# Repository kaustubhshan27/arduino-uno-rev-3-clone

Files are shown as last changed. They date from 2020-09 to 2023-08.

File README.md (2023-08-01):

# Arduino-Uno-Rev-3-Clone
Implemented an Arduino Uno Rev 3 PCB clone using Altium Designer. All component symbols and footprints were made from scratch.

## Assembly View
Screenshot from 2023-08-01 13-02-20

## Schematic
Screenshot from 2023-08-01 13-00-51

## 3D
Screenshot from 2023-08-01 13-01-30

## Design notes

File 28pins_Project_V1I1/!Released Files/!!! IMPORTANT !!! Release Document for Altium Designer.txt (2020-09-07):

Follow this procedure before releasing files. Confirm every action with your initials and date.
IF ANY CHANGES NEEDS TO BE DONE, START THE PROCEDURE FROM BEGINNING!

The procedure needs to be executed in order as defined here. Start from number 1
--------------------------------------------------------------------------------

1) Right Click on the project -> Compile PCB project
I confirm, the project compiles with no errors: 
KS [07-09-2020]

2) Run Design -> Update PCB Document
I confirm, there are no differences between Schematic and PCB: 
KS [07-09-2020]

3) Impedance
I confirm, I have updated and check track width/gap to match required impedance (e.g 55 OHMs): 
NA

4) Run Tools -> Polygon Pours -> Rebuild All
I confirm, all polygons have been repoured: 
KS [07-09-2020]

5) Run Tools -> Design Rule Check -> Run Design Rule Check
I confirm, I have checked Design Rule Output File:
KS [07-09-2020]

6) Gerber check
I confirm, I have copied and visually checked gerber files placed in \PCB Manufacturing\Gerber Output\
KS [07-09-2020]

7) Other files
I confirm, I have copied and checked files placed in subdirectories:
KS [07-09-2020]

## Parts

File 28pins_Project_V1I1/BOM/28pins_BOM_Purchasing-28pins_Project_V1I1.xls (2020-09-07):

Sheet: Part List Report
 | Component list |  |  | 28pins_BOM_Purchasing for Project [28pins_Project_V1I1.PrjPcb] (No PCB Document Selected)
 | Source Data From: | 28pins_Project_V1I1.PrjPcb |  |  | Contact: |  |  |  | Generated by:
 | Project: | 28pins_Project_V1I1.PrjPcb
 | Variant: | None |  |  |  |  |  |  | FEDEVEL
 | Report Date: | 30-Aug-20 | 10:42 PM |  |  |  |  |  | http://www.fedevel.com
 | Print Date: | 2020-08-30 | 22:42:14
# | Category | Manufacturer 1 | Manufacturer Part Number 1 | #Column Name Error:' Package / Case | Description | Quantity | Supplier 1 | Supplier Part Number 1 | Supplier Order Qty 1 | Supplier Stock 1 | Supplier Unit Price 1 | Supplier Subtotal 1 | Supplier Currency 1
1 | Aluminum Electrolytic Capacitors | Panasonic | EEE-1AA101WR |  | Cap Aluminum 100uF 10V 20% (5 X 5.4mm) SMD 50mA 1000 hr 85°C T/R | 2 | Digi-Key | PCE3867CT-ND | 2 | 0 | 0.30 | 0.60 | USD
2 | Ceramic Capacitors | TDK | C2012X5R1C106M125AC |  | CERAMIC CAPACITOR, 10UF, 16V, X5R, 20%, 0805, FULL REEL; Product Range:C Series; Capacitance:10 F; Capacitance Tolerance: 20%; Dielectric Characteristic:X5R; Voltage Rating:16V; Ceramic Capacitor Case:0805 [2012 Metric]; MSL:- ;RoHS Compliant: Yes | 7 | Digi-Key | 445-4115-2-ND |  | 0
3 | Ceramic Capacitors | TDK | C2012X7R1H104K085AA |  | TDK - C2012X7R1H104K085AA - SMD Multilayer Ceramic Capacitor, 0.1 µF, 50 V, 0805 [2012 Metric], ± 10%, X7R, C Series | 19 | Digi-Key | 445-7534-1-ND | 19 | 0 | 0.11 | 2.17 | USD
4 | Ceramic Capacitors | TDK | C2012X5R1E105K125AA |  | TDK - C2012X5R1E105K125AA - SMD Multilayer Ceramic Capacitor, 1 µF, 25 V, 0805 [2012 Metric], ± 10%, X5R, C Series | 1 | Digi-Key | 445-1419-1-ND | 1 | 10418 | 0.26 | 0.26 | USD
5 | Ceramic Capacitors | KEMET | C0805C180J5GACTU |  | CAP CER 18PF 50V C0G/NP0 0805 | 4 | Digi-Key | 399-1112-1-ND | 4 | 107048 | 0.13 | 0.52 | USD
6 | Uncategorized | Osram Opto | LGL29K-G2J1-24-Z |  | LED Uni-Color Green 572nm 2-Pin Chip 0603(1608Metric) T/R | 1 | Digi-Key | 475-2709-1-ND | 1 | 0 | 0.42 | 0.42 | USD
7 | Uncategorized | Osram Opto | LOL29K-H2K1-24-Z |  | OSRAM - LO L29K-H2K1-24-Z - SMARTLED 0603 ORANGE | 3 | Digi-Key | 475-2740-2-ND |  | 0
8 | Schottky Diodes | ON Semiconductor / Fairchild | BAT54HT1G |  | Small Signal Schottky Diode, Single, 30 V, 200 mA, 800 mV, 600 mA, 150 C ;RoHS Compliant: Yes | 2 | Digi-Key | BAT54HT1GOSCT-ND | 2 | 217747 | 0.20 | 0.40 | USD
9 | Ferrite Beads and Chips | TDK | MPZ2012S601AT000 |  | FERRITE BEAD 600 OHM 0805 1LN | 3 | Digi-Key | 445-2206-1-ND | 3 | 217659 | 0.11 | 0.33 | USD
10 | Headers and Wire Housings | Harwin | M20-7820842 |  | 2.54mm (0.1") Pitch SIL Vertical PC Tail Socket Assembly, selective gold + tin, 8 contacts | 2 | Digi-Key | 952-1823-ND | 2 | 1791 | 1.10 | 2.20 | USD
11 | Headers and Wire Housings | Harwin | M20-7820646 |  | 06-WAY SIL VERT SOCKET L/FREE | 1 | Digi-Key | 952-1809-ND | 1 | 2278 | 0.96 | 0.96 | USD
12 | Headers and Wire Housings | Harwin | M20-7821046 |  | HARWIN - M20-7821046 - Board-To-Board Connector, M20 Series, Through Hole, Receptacle, 10, 2.54 mm, Tin Plated Contacts | 1 | Digi-Key | 952-1847-ND | 1 | 554 | 1.28 | 1.28 | USD
13 | Headers and Wire Housings | Harwin | M20-9980346 |  | Conn Unshrouded Header HDR 6 POS 2.54mm Solder ST Thru-Hole Bag | 2 | Digi-Key | 952-2121-ND | 2 | 18299 | 0.24 | 0.48 | USD
14 | USB Connectors | AMPHENOL ICC (FCI) | 10118193-0001LF |  | CONN USB MICRO B RECPT SMT R/A | 1 | Digi-Key | 609-4616-1-ND | 1 | 126829 | 0.43 | 0.43 | USD
15 | Headers and Wire Housings | Harwin | M20-9990346 |  | CONN HEADER VERT 3POS 2.54MM | 2 | Digi-Key | 952-2264-ND | 2 | 11198 | 0.15 | 0.30 | USD
16 | Headers and Wire Housings | Amphenol ICC | 68602-204HLF |  | CONN HEADER VERT 4POS 2.54MM | 1 | Digi-Key | 609-3369-ND | 1 | 3699 | 0.34 | 0.34 | USD
17 | Headers and Wire Housings | Harwin | M20-9990446 |  | 04 SIL Vert Pin Hdr | 1 | Digi-Key | 952-2266-ND | 1 | 10513 | 0.19 | 0.19 | USD
18 | Fixed Inductors | KEMET | L1210R2R2MDWIT |  | FIXED IND 2.2UH 2A 80 MOHM SMD | 1 | Digi-Key | 399-9598-1-ND | 1 | 0 | 0.50 | 0.50 | USD
19 | Connectors | Sullins | QPC02SXGN-RC |  | CONN JUMPER SHORTING .100" GOLD | 3 | Digi-Key | S9337-ND | 3 | 588896 | 0.10 | 0.30 | USD
20 | Chip SMD Resistors | Yageo | RC0805FR-07100KL |  | YAGEO RC0805FR-07100KL RES, THICK FILM, 100K, 1%, 0.125W, 0805, REEL | 1 | Digi-Key | 311-100KCRCT-ND | 1 | 3710722 | 0.10 | 0.10 | USD
21 | Chip SMD Resistors | Yageo | RC0805FR-07560RL |  | Surface Mount Thick Film Resistor, RC Series, 560 ohm, 125 mW, - 1%, 150 V, 0805 [2012 Metric] | 5 | Digi-Key | 311-560CRCT-ND | 5 | 75023 | 0.10 | 0.50 | USD
22 | Chip SMD Resistors | Yageo | RC0805FR-0710KL |  | RES SMD 10K OHM 1% 1/8W 0805 | 6 | Digi-Key | 311-10.0KCRCT-ND | 6 | 19063106 | 0.10 | 0.60 | USD
23 | Chip SMD Resistors | Yageo | RC0805FR-0722RL |  | RES SMD 22 OHM 1% 1/8W 0805 | 7 | Digi-Key | 311-22.0CRCT-ND | 7 | 736981 | 0.10 | 0.70 | USD
24 | Chip SMD Resistors | Yageo | RC0805JR-070RL |  | Surface Mount Thick Film Resistor, RC Series, 125 mW, - 5%, 150 V, 0805 [2012 Metric] | 4 | Digi-Key | 311-0.0ARCT-ND | 4 | 6537793 | 0.10 | 0.40 | USD
25 | Chip SMD Resistors | Yageo | RC0805FR-071ML |  | RES SMD 1M OHM 1% 1/8W 0805 | 2 | Digi-Key | 311-1.00MCRCT-ND | 2 | 2931267 | 0.10 | 0.20 | USD
26 | Chip SMD Resistors | Yageo | RC0805FR-071KL |  | RESISTOR, 0805 1K 1%, FULL REEL; Product Range:YAGEO - RC Series; Resistance:1kohm; Power Rating:125mW; Resistance Tolerance:± 1%; Resistor Case Style:0805 [2012 Metric]; Resistor Element Material:Thick Film; Temperature Coefficient:± 250ppm/°C; Voltage Rating:150V; Packaging:Tape & Reel; MSL:-; SVHC:No SVHC (16-Dec-2013); External Depth:0.55mm; External Length / Height:2mm; External Width:1.25mm; No. of Pins:2; Operating Temperature Max:155°C; Operating Temperature Min:-55°C; Operating Temperature Range:-55°C to +155°C; Reel Quantity:5000; Resistor Mounting:SMD; Series:RC12H; Temperature Coef | 3 | Digi-Key | 311-1.00KCRCT-ND | 3 | 17310766 | 0.10 | 0.30 | USD
27 | Connectors | 3M | 7010501790 |  | CONN IC DIP SOCKET 28POS TIN | 1 | Digi-Key | 3M5480-ND | 1 | 4178 | 0.79 | 0.79 | USD
28 | Pushbutton Switches | TE Connectivity | FSM4JH |  | SWITCH TACTILE SPST-NO 0.05A 24V | 2 | Digi-Key | 450-1650-ND | 2 | 94987 | 0.10 | 0.20 | USD
29 | Microcontrollers | Microchip / Atmel | ATMEGA328P-PU |  | ATMEGA328P-PU; 8 bit Microcontroller AVR 20MHz 1; 32kb Flash; 2kb RAM; I2C SPI 2 | 1 | Digi-Key | ATMEGA328P-PU-ND | 1 | 4823 | 2.08 | 2.08 | USD
30 | Microcontrollers | Microchip | ATMEGA16U2-AU |  | MICROCHIP - ATMEGA16U2-AU - MCU, 8BIT, MEGAAVR, 16MHZ, TQFP-32 | 1 | Digi-Key | ATMEGA16U2-AU-ND | 1 | 3865 | 2.45 | 2.45 | USD
31 | Voltage Regulators - Linear | Texas Instruments | TL1963A-33DCQR |  | IC REG LINEAR 3.3V 1.5A SOT223-6 | 1 | Digi-Key | 296-24534-1-ND | 1 | 2906 | 2.80 | 2.80 | USD
32 | Logic Gates | Texas Instruments | SN74AHC1G09DBVR |  | TEXAS INSTRUMENTS - SN74AHC1G09DBVR - AND Gate, 74AHC1G09, 2 Input, 2 V to 5.5 V, SOT-23-5 | 4 | Digi-Key | 296-29202-1-ND | 4 | 30506 | 0.32 | 1.28 | USD
33 | Crystals | Abracon | ABM7-16.000MHZ-D2Y-T |  | CRYSTAL 16.0000MHZ 18PF SMD | 2 | Digi-Key | 535-9840-1-ND | 2 | 61243 | 1.00 | 2.00 | USD
34 | Varistors | Bourns | CG0603MLC-05E |  | VARISTOR 0603 | 2 | Digi-Key | CG0603MLC-05ECT-ND | 2 | 106625 | 0.10 | 0.20 | USD
 |  |  |  |  |  | 99 |  |  | 89 |  |  | 26.28
Approved |  |  |  | Notes
 |  |  |  |  |  | 1 | pcs: | Total |  | 26.28 |  | USD
 |  |  |  |  |  |  |  | Price for 1pcs |  | 26.28 |  | USD

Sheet: Project Information
Project Full Path | C:\Users\Public\Documents\Altium\Projects\28pins_Project_V1I1\28pins_Project_V1I1.PrjPcb
Project Filename | 28pins_Project_V1I1.PrjPcb
Variant Name | None
Data-Source Filename | 28pins_Project_V1I1.PrjPcb
Data-Source Full Path | C:\Users\Public\Documents\Altium\Projects\28pins_Project_V1I1\28pins_Project_V1I1.PrjPcb
Title | 28pins_BOM_Purchasing for Project [28pins_Project_V1I1.PrjPcb] (No PCB Document Selected)
Total Quantity | 99
Report Time | 10:42 PM
Report Date | 30-Aug-20
Report Date & Tine | 30-Aug-20 10:42 PM
Output Name | 28pins_BOM_Purchasing
Output Type | BOM_PartType
Output Generator Name | BOM
Output Generator Description | Bill of Materials

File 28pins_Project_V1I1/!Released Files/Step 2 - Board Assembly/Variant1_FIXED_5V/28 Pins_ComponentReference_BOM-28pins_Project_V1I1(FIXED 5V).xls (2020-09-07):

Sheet: Part List Report
 | Component reference list |  |  | <Parameter Project not found>
 |  | Source Data From: | 28pins_Project_V1I1.PrjPcb |  | Contact: |  | Generated by:
 |  | Project: | 28pins_Project_V1I1.PrjPcb
 |  | Variant: | FIXED 5V |  |  |  | FEDEVEL
 | Report Date: | 07-Sep-20 | 11:49 AM |  |  |  | http://www.fedevel.com
 | Print Date: | 2020-09-07 | 11:49:17
# | Designator | Comment | Description | Manufacturer 1 | Manufacturer Part Number 1 | #Column Name Error:' Package / Case | Supplier 1 | Supplier Part Number 1
1 | C1 | 100uF/10V | Cap Aluminum 100uF 10V 20% (5 X 5.4mm) SMD 50mA 1000 hr 85°C T/R |  |  |  | Digi-Key | PCE3867CT-ND
2 | C2 | 100uF/10V | Cap Aluminum 100uF 10V 20% (5 X 5.4mm) SMD 50mA 1000 hr 85°C T/R |  |  |  | Digi-Key | PCE3867CT-ND
3 | C3 | 10uF/16V | CERAMIC CAPACITOR, 10UF, 16V, X5R, 20%, 0805, FULL REEL; Product Range:C Series; Capacitance:10 F; Capacitance Tolerance: 20%; Dielectric Characteristic:X5R; Voltage Rating:16V; Ceramic Capacitor Case:0805 [2012 Metric]; MSL:- ;RoHS Compliant: Yes |  |  |  | Digi-Key | 445-4115-2-ND
4 | C4 | 100nF/50V | TDK - C2012X7R1H104K085AA - SMD Multilayer Ceramic Capacitor, 0.1 µF, 50 V, 0805 [2012 Metric], ± 10%, X7R, C Series |  |  |  | Digi-Key | 445-7534-1-ND
5 | C5 | 100nF/50V | TDK - C2012X7R1H104K085AA - SMD Multilayer Ceramic Capacitor, 0.1 µF, 50 V, 0805 [2012 Metric], ± 10%, X7R, C Series |  |  |  | Digi-Key | 445-7534-1-ND
6 | C6 | 100nF/50V | TDK - C2012X7R1H104K085AA - SMD Multilayer Ceramic Capacitor, 0.1 µF, 50 V, 0805 [2012 Metric], ± 10%, X7R, C Series |  |  |  | Digi-Key | 445-7534-1-ND
7 | C7 | 1uF/25V | TDK - C2012X5R1E105K125AA - SMD Multilayer Ceramic Capacitor, 1 µF, 25 V, 0805 [2012 Metric], ± 10%, X5R, C Series |  |  |  | Digi-Key | 445-1419-1-ND
8 | C8 | 100nF/50V | TDK - C2012X7R1H104K085AA - SMD Multilayer Ceramic Capacitor, 0.1 µF, 50 V, 0805 [2012 Metric], ± 10%, X7R, C Series |  |  |  | Digi-Key | 445-7534-1-ND
9 | C9 | 18pF/50V | CAP CER 18PF 50V C0G/NP0 0805 |  |  |  | Digi-Key | 399-1112-1-ND
10 | C10 | 18pF/50V | CAP CER 18PF 50V C0G/NP0 0805 |  |  |  | Digi-Key | 399-1112-1-ND
11 | C11 | 100nF/50V | TDK - C2012X7R1H104K085AA - SMD Multilayer Ceramic Capacitor, 0.1 µF, 50 V, 0805 [2012 Metric], ± 10%, X7R, C Series |  |  |  | Digi-Key | 445-7534-1-ND
12 | C12 | 10uF/16V | CERAMIC CAPACITOR, 10UF, 16V, X5R, 20%, 0805, FULL REEL; Product Range:C Series; Capacitance:10 F; Capacitance Tolerance: 20%; Dielectric Characteristic:X5R; Voltage Rating:16V; Ceramic Capacitor Case:0805 [2012 Metric]; MSL:- ;RoHS Compliant: Yes |  |  |  | Digi-Key | 445-4115-2-ND
13 | C13 | 10uF/16V | CERAMIC CAPACITOR, 10UF, 16V, X5R, 20%, 0805, FULL REEL; Product Range:C Series; Capacitance:10 F; Capacitance Tolerance: 20%; Dielectric Characteristic:X5R; Voltage Rating:16V; Ceramic Capacitor Case:0805 [2012 Metric]; MSL:- ;RoHS Compliant: Yes |  |  |  | Digi-Key | 445-4115-2-ND
14 | C14 | 100nF/50V | TDK - C2012X7R1H104K085AA - SMD Multilayer Ceramic Capacitor, 0.1 µF, 50 V, 0805 [2012 Metric], ± 10%, X7R, C Series |  |  |  | Digi-Key | 445-7534-1-ND
15 | C15 | 100nF/50V | TDK - C2012X7R1H104K085AA - SMD Multilayer Ceramic Capacitor, 0.1 µF, 50 V, 0805 [2012 Metric], ± 10%, X7R, C Series |  |  |  | Digi-Key | 445-7534-1-ND
16 | C16 | 100nF/50V | TDK - C2012X7R1H104K085AA - SMD Multilayer Ceramic Capacitor, 0.1 µF, 50 V, 0805 [2012 Metric], ± 10%, X7R, C Series |  |  |  | Digi-Key | 445-7534-1-ND
17 | C17 | 100nF/50V | TDK - C2012X7R1H104K085AA - SMD Multilayer Ceramic Capacitor, 0.1 µF, 50 V, 0805 [2012 Metric], ± 10%, X7R, C Series |  |  |  | Digi-Key | 445-7534-1-ND
18 | C19 | 10uF/16V | CERAMIC CAPACITOR, 10UF, 16V, X5R, 20%, 0805, FULL REEL; Product Range:C Series; Capacitance:10 F; Capacitance Tolerance: 20%; Dielectric Characteristic:X5R; Voltage Rating:16V; Ceramic Capacitor Case:0805 [2012 Metric]; MSL:- ;RoHS Compliant: Yes |  |  |  | Digi-Key | 445-4115-2-ND
19 | C20 | 100nF/50V | TDK - C2012X7R1H104K085AA - SMD Multilayer Ceramic Capacitor, 0.1 µF, 50 V, 0805 [2012 Metric], ± 10%, X7R, C Series |  |  |  | Digi-Key | 445-7534-1-ND
20 | C21 | 10uF/16V | CERAMIC CAPACITOR, 10UF, 16V, X5R, 20%, 0805, FULL REEL; Product Range:C Series; Capacitance:10 F; Capacitance Tolerance: 20%; Dielectric Characteristic:X5R; Voltage Rating:16V; Ceramic Capacitor Case:0805 [2012 Metric]; MSL:- ;RoHS Compliant: Yes |  |  |  | Digi-Key | 445-4115-2-ND
21 | C22 | 10uF/16V | CERAMIC CAPACITOR, 10UF, 16V, X5R, 20%, 0805, FULL REEL; Product Range:C Series; Capacitance:10 F; Capacitance Tolerance: 20%; Dielectric Characteristic:X5R; Voltage Rating:16V; Ceramic Capacitor Case:0805 [2012 Metric]; MSL:- ;RoHS Compliant: Yes |  |  |  | Digi-Key | 445-4115-2-ND
22 | C23 | 100nF/50V | TDK - C2012X7R1H104K085AA - SMD Multilayer Ceramic Capacitor, 0.1 µF, 50 V, 0805 [2012 Metric], ± 10%, X7R, C Series |  |  |  | Digi-Key | 445-7534-1-ND
23 | C24 | 100nF/50V | TDK - C2012X7R1H104K085AA - SMD Multilayer Ceramic Capacitor, 0.1 µF, 50 V, 0805 [2012 Metric], ± 10%, X7R, C Series |  |  |  | Digi-Key | 445-7534-1-ND
24 | C25 | 18pF/50V | CAP CER 18PF 50V C0G/NP0 0805 |  |  |  | Digi-Key | 399-1112-1-ND
25 | C26 | 100nF/50V | TDK - C2012X7R1H104K085AA - SMD Multilayer Ceramic Capacitor, 0.1 µF, 50 V, 0805 [2012 Metric], ± 10%, X7R, C Series |  |  |  | Digi-Key | 445-7534-1-ND
26 | C27 | 18pF/50V | CAP CER 18PF 50V C0G/NP0 0805 |  |  |  | Digi-Key | 399-1112-1-ND
27 | C28 | 100nF/50V | TDK - C2012X7R1H104K085AA - SMD Multilayer Ceramic Capacitor, 0.1 µF, 50 V, 0805 [2012 Metric], ± 10%, X7R, C Series |  |  |  | Digi-Key | 445-7534-1-ND
28 | C29 | 100nF/50V | TDK - C2012X7R1H104K085AA - SMD Multilayer Ceramic Capacitor, 0.1 µF, 50 V, 0805 [2012 Metric], ± 10%, X7R, C Series |  |  |  | Digi-Key | 445-7534-1-ND
29 | C30 | 100nF/50V | TDK - C2012X7R1H104K085AA - SMD Multilayer Ceramic Capacitor, 0.1 µF, 50 V, 0805 [2012 Metric], ± 10%, X7R, C Series |  |  |  | Digi-Key | 445-7534-1-ND
30 | C31 | 100nF/50V | TDK - C2012X7R1H104K085AA - SMD Multilayer Ceramic Capacitor, 0.1 µF, 50 V, 0805 [2012 Metric], ± 10%, X7R, C Series |  |  |  | Digi-Key | 445-7534-1-ND
31 | C32 | 100nF/50V | TDK - C2012X7R1H104K085AA - SMD Multilayer Ceramic Capacitor, 0.1 µF, 50 V, 0805 [2012 Metric], ± 10%, X7R, C Series |  |  |  | Digi-Key | 445-7534-1-ND
32 | C33 | 100nF/50V | TDK - C2012X7R1H104K085AA - SMD Multilayer Ceramic Capacitor, 0.1 µF, 50 V, 0805 [2012 Metric], ± 10%, X7R, C Series |  |  |  | Digi-Key | 445-7534-1-ND
33 | C34 | 10uF/16V | CERAMIC CAPACITOR, 10UF, 16V, X5R, 20%, 0805, FULL REEL; Product Range:C Series; Capacitance:10 F; Capacitance Tolerance: 20%; Dielectric Characteristic:X5R; Voltage Rating:16V; Ceramic Capacitor Case:0805 [2012 Metric]; MSL:- ;RoHS Compliant: Yes |  |  |  | Digi-Key | 445-4115-2-ND
34 | D1 | Green | LED Uni-Color Green 572nm 2-Pin Chip 0603(1608Metric) T/R |  |  |  | Digi-Key | 475-2709-1-ND
35 | D2 | Orange | OSRAM - LO L29K-H2K1-24-Z - SMARTLED 0603 ORANGE |  |  |  | Digi-Key | 475-2740-2-ND
36 | D3 | Orange | OSRAM - LO L29K-H2K1-24-Z - SMARTLED 0603 ORANGE |  |  |  | Digi-Key | 475-2740-2-ND
37 | D4 | Orange | OSRAM - LO L29K-H2K1-24-Z - SMARTLED 0603 ORANGE |  |  |  | Digi-Key | 475-2740-2-ND
38 | D5 | BAT54HT1G | Small Signal Schottky Diode, Single, 30 V, 200 mA, 800 mV, 600 mA, 150 C ;RoHS Compliant: Yes |  |  |  | Digi-Key | BAT54HT1GOSCT-ND
39 | D6 | BAT54HT1G | Small Signal Schottky Diode, Single, 30 V, 200 mA, 800 mV, 600 mA, 150 C ;RoHS Compliant: Yes |  |  |  | Digi-Key | BAT54HT1GOSCT-ND
40 | FB1 | MPZ2012S601AT000 | FERRITE BEAD 600 OHM 0805 1LN |  |  |  | Digi-Key | 445-2206-1-ND
41 | FB2 | MPZ2012S601AT000 | FERRITE BEAD 600 OHM 0805 1LN |  |  |  | Digi-Key | 445-2206-1-ND
42 | FB3 | MPZ2012S601AT000 | FERRITE BEAD 600 OHM 0805 1LN |  |  |  | Digi-Key | 445-2206-1-ND
43 | J1 | HDR FEMALE 1x8 2.54mm | 2.54mm (0.1") Pitch SIL Vertical PC Tail Socket Assembly, selective gold + tin, 8 contacts |  |  |  | Digi-Key | 952-1823-ND
44 | J2 | HDR FEMALE 1x6 2.54mm | 06-WAY SIL VERT SOCKET L/FREE |  |  |  | Digi-Key | 952-1809-ND
45 | J3 | HDR FEMALE 1x8 2.54mm | 2.54mm (0.1") Pitch SIL Vertical PC Tail Socket Assembly, selective gold + tin, 8 contacts |  |  |  | Digi-Key | 952-1823-ND
46 | J4 | HDR FEMALE 1x10 2.54mm | HARWIN - M20-7821046 - Board-To-Board Connector, M20 Series, Through Hole, Receptacle, 10, 2.54 mm, Tin Plated Contacts |  |  |  | Digi-Key | 952-1847-ND
47 | J5 | HDR_MALE_2x3 | Conn Unshrouded Header HDR 6 POS 2.54mm Solder ST Thru-Hole Bag |  |  |  | Digi-Key | 952-2121-ND
48 | J6 | HDR_MALE_2x3 | Conn Unshrouded Header HDR 6 POS 2.54mm Solder ST Thru-Hole Bag |  |  |  | Digi-Key | 952-2121-ND
49 | J7 | 10118193-0001LF | CONN USB MICRO B RECPT SMT R/A |  |  |  | Digi-Key | 609-4616-1-ND
50 | JP1 | HDR_MALE_1x3 | CONN HEADER VERT 3POS 2.54MM |  |  |  | Digi-Key | 952-2264-ND
51 | JP3 | HDR_MALE_1x4 | 04 SIL Vert Pin Hdr |  |  |  | Digi-Key | 952-2266-ND
52 | L1 | 2u2/2A | FIXED IND 2.2UH 2A 80 MOHM SMD |  |  |  | Digi-Key | 399-9598-1-ND
53 | LINK1 | LINK | CONN JUMPER SHORTING .100" GOLD |  |  |  | Digi-Key | S9337-ND
54 | LINK2 | LINK | CONN JUMPER SHORTING .100" GOLD |  |  |  | Digi-Key | S9337-ND
55 | R1 | 100k | YAGEO RC0805FR-07100KL RES, THICK FILM, 100K, 1%, 0.125W, 0805, REEL |  |  |  | Digi-Key | 311-100KCRCT-ND
56 | R2 | 560 | Surface Mount Thick Film Resistor, RC Series, 560 ohm, 125 mW, - 1%, 150 V, 0805 [2012 Metric] |  |  |  | Digi-Key | 311-560CRCT-ND
57 | R3 | 560 | Surface Mount Thick Film Resistor, RC Series, 560 ohm, 125 mW, - 1%, 150 V, 0805 [2012 Metric] |  |  |  | Digi-Key | 311-560CRCT-ND
58 | R4 | 10k | RES SMD 10K OHM 1% 1/8W 0805 |  |  |  | Digi-Key | 311-10.0KCRCT-ND
59 | R5 | 22 | RES SMD 22 OHM 1% 1/8W 0805 |  |  |  | Digi-Key | 311-22.0CRCT-ND
60 | R6 | 22 | RES SMD 22 OHM 1% 1/8W 0805 |  |  |  | Digi-Key | 311-22.0CRCT-ND
61 | R7 | 22 | RES SMD 22 OHM 1% 1/8W 0805 |  |  |  | Digi-Key | 311-22.0CRCT-ND
62 | R8 | 0 | Surface Mount Thick Film Resistor, RC Series, 125 mW, - 5%, 150 V, 0805 [2012 Metric] |  |  |  | Digi-Key | 311-0.0ARCT-ND
63 | R9 | 1M | RES SMD 1M OHM 1% 1/8W 0805 |  |  |  | Digi-Key | 311-1.00MCRCT-ND
64 | R10 | 1k | RESISTOR, 0805 1K 1%, FULL REEL; Product Range:YAGEO - RC Series; Resistance:1kohm; Power Rating:125mW; Resistance Tolerance:± 1%; Resistor Case Style:0805 [2012 Metric]; Resistor Element Material:Thick Film; Temperature Coefficient:± 250ppm/°C; Voltage Rating:150V; Packaging:Tape & Reel; MSL:-; SVHC:No SVHC (16-Dec-2013); External Depth:0.55mm; External Length / Height:2mm; External Width:1.25mm; No. of Pins:2; Operating Temperature Max:155°C; Operating Temperature Min:-55°C; Operating Temperature Range:-55°C to +155°C; Reel Quantity:5000; Resistor Mounting:SMD; Series:RC12H; Temperature Coef |  |  |  | Digi-Key | 311-1.00KCRCT-ND
65 | R11 | 1k | RESISTOR, 0805 1K 1%, FULL REEL; Product Range:YAGEO - RC Series; Resistance:1kohm; Power Rating:125mW; Resistance Tolerance:± 1%; Resistor Case Style:0805 [2012 Metric]; Resistor Element Material:Thick Film; Temperature Coefficient:± 250ppm/°C; Voltage Rating:150V; Packaging:Tape & Reel; MSL:-; SVHC:No SVHC (16-Dec-2013); External Depth:0.55mm; External Length / Height:2mm; External Width:1.25mm; No. of Pins:2; Operating Temperature Max:155°C; Operating Temperature Min:-55°C; Operating Temperature Range:-55°C to +155°C; Reel Quantity:5000; Resistor Mounting:SMD; Series:RC12H; Temperature Coef |  |  |  | Digi-Key | 311-1.00KCRCT-ND
66 | R12 | 1k | RESISTOR, 0805 1K 1%, FULL REEL; Product Range:YAGEO - RC Series; Resistance:1kohm; Power Rating:125mW; Resistance Tolerance:± 1%; Resistor Case Style:0805 [2012 Metric]; Resistor Element Material:Thick Film; Temperature Coefficient:± 250ppm/°C; Voltage Rating:150V; Packaging:Tape & Reel; MSL:-; SVHC:No SVHC (16-Dec-2013); External Depth:0.55mm; External Length / Height:2mm; External Width:1.25mm; No. of Pins:2; Operating Temperature Max:155°C; Operating Temperature Min:-55°C; Operating Temperature Range:-55°C to +155°C; Reel Quantity:5000; Resistor Mounting:SMD; Series:RC12H; Temperature Coef |  |  |  | Digi-Key | 311-1.00KCRCT-ND
67 | R13 | 22 | RES SMD 22 OHM 1% 1/8W 0805 |  |  |  | Digi-Key | 311-22.0CRCT-ND
68 | R14 | 10k | RES SMD 10K OHM 1% 1/8W 0805 |  |  |  | Digi-Key | 311-10.0KCRCT-ND
69 | R15 | 560 | Surface Mount Thick Film Resistor, RC Series, 560 ohm, 125 mW, - 1%, 150 V, 0805 [2012 Metric] |  |  |  | Digi-Key | 311-560CRCT-ND
70 | R16 | 1M | RES SMD 1M OHM 1% 1/8W 0805 |  |  |  | Digi-Key | 311-1.00MCRCT-ND
71 | R17 | 560 | Surface Mount Thick Film Resistor, RC Series, 560 ohm, 125 mW, - 1%, 150 V, 0805 [2012 Metric] |  |  |  | Digi-Key | 311-560CRCT-ND
72 | R18 | 10k | RES SMD 10K OHM 1% 1/8W 0805 |  |  |  | Digi-Key | 311-10.0KCRCT-ND
73 | R19 | 10k | RES SMD 10K OHM 1% 1/8W 0805 |  |  |  | Digi-Key | 311-10.0KCRCT-ND
74 | R20 | 10k | RES SMD 10K OHM 1% 1/8W 0805 |  |  |  | Digi-Key | 311-10.0KCRCT-ND
75 | R21 | 10k | RES SMD 10K OHM 1% 1/8W 0805 |  |  |  | Digi-Key | 311-10.0KCRCT-ND
76 | R22 | 560 | Surface Mount Thick Film Resistor, RC Series, 560 ohm, 125 mW, - 1%, 150 V, 0805 [2012 Metric] |  |  |  | Digi-Key | 311-560CRCT-ND
77 | R23 | 22 | RES SMD 22 OHM 1% 1/8W 0805 |  |  |  | Digi-Key | 311-22.0CRCT-ND
78 | R24 | 22 | RES SMD 22 OHM 1% 1/8W 0805 |  |  |  | Digi-Key | 311-22.0CRCT-ND
79 | R25 | 22 | RES SMD 22 OHM 1% 1/8W 0805 |  |  |  | Digi-Key | 311-22.0CRCT-ND
80 | R27 | 0 | Surface Mount Thick Film Resistor, RC Series, 125 mW, - 5%, 150 V, 0805 [2012 Metric] |  |  |  | Digi-Key | 311-0.0ARCT-ND
81 | SCKET FOR U1 | 28 Pin DIP Socket | CONN IC DIP SOCKET 28POS TIN |  |  |  | Digi-Key | 3M5480-ND
82 | SW1 | 1825910-6 | SWITCH TACTILE SPST-NO 0.05A 24V |  |  |  | Digi-Key | 450-1650-ND
83 | SW2 | 1825910-6 | SWITCH TACTILE SPST-NO 0.05A 24V |  |  |  | Digi-Key | 450-1650-ND
84 | U1 | ATMEGA328P-PU | ATMEGA328P-PU; 8 bit Microcontroller AVR 20MHz 1; 32kb Flash; 2kb RAM; I2C SPI 2 |  |  |  | Digi-Key | ATMEGA328P-PU-ND
85 | U2 | ATMEGA16U2-AU | MICROCHIP - ATMEGA16U2-AU - MCU, 8BIT, MEGAAVR, 16MHZ, TQFP-32 |  |  |  | Digi-Key | ATMEGA16U2-AU-ND
86 | U3 | TL1963A-33DCQR | IC REG LINEAR 3.3V 1.5A SOT223-6 |  |  |  | Digi-Key | 296-24534-1-ND
87 | U4 | SN74AHC1G09DBVR | TEXAS INSTRUMENTS - SN74AHC1G09DBVR - AND Gate, 74AHC1G09, 2 Input, 2 V to 5.5 V, SOT-23-5 |  |  |  | Digi-Key | 296-29202-1-ND
88 | U5 | SN74AHC1G09DBVR | TEXAS INSTRUMENTS - SN74AHC1G09DBVR - AND Gate, 74AHC1G09, 2 Input, 2 V to 5.5 V, SOT-23-5 |  |  |  | Digi-Key | 296-29202-1-ND
89 | U6 | SN74AHC1G09DBVR | TEXAS INSTRUMENTS - SN74AHC1G09DBVR - AND Gate, 74AHC1G09, 2 Input, 2 V to 5.5 V, SOT-23-5 |  |  |  | Digi-Key | 296-29202-1-ND
90 | U7 | SN74AHC1G09DBVR | TEXAS INSTRUMENTS - SN74AHC1G09DBVR - AND Gate, 74AHC1G09, 2 Input, 2 V to 5.5 V, SOT-23-5 |  |  |  | Digi-Key | 296-29202-1-ND
91 | Y1 | ABM7-16.000MHZ-D2Y-T | CRYSTAL 16.0000MHZ 18PF SMD |  |  |  | Digi-Key | 535-9840-1-ND
92 | Y2 | ABM7-16.000MHZ-D2Y-T | CRYSTAL 16.0000MHZ 18PF SMD |  |  |  | Digi-Key | 535-9840-1-ND
93 | Z1 | CG0603MLC-05E | VARISTOR 0603 |  |  |  | Digi-Key | CG0603MLC-05ECT-ND
94 | Z2 | CG0603MLC-05E | VARISTOR 0603 |  |  |  | Digi-Key | CG0603MLC-05ECT-ND
Approved |  |  |  | Notes

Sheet: Project Information
Project Full Path | C:\Users\Public\Documents\Altium\Projects\28pins_Project_V1I1\28pins_Project_V1I1.PrjPcb
Project Filename | 28pins_Project_V1I1.PrjPcb
Variant Name | FIXED 5V
Data-Source Filename | 28pins_Project_V1I1.PrjPcb
Data-Source Full Path | C:\Users\Public\Documents\Altium\Projects\28pins_Project_V1I1\28pins_Project_V1I1.PrjPcb
Title | 28pins_Project_V1I1.PrjPcb
Total Quantity | 94
Report Time | 11:49 AM
Report Date | 07-Sep-20
Report Date & Tine | 07-Sep-20 11:49 AM
Output Name | 28 Pins_ComponentReference_BOM
Output Type | BOM_PartType
Output Generator Name | BOM
Output Generator Description | Bill of Materials

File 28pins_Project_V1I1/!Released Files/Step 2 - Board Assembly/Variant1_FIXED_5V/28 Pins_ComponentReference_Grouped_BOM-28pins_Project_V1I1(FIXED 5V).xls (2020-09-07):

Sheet: Part List Report
 | Component reference list (grouped) |  |  |  | <Parameter Project not found>
 | Source Data From: |  | 28pins_Project_V1I1.PrjPcb |  |  | Contact: |  | Generated by:
 | Project: |  | 28pins_Project_V1I1.PrjPcb
 | Variant: |  | FIXED 5V |  |  |  |  | FEDEVEL
 | Report Date: |  | 07-Sep-20 | 11:57 AM |  |  |  | http://www.fedevel.com
 | Print Date: |  | 2020-09-07 | 11:57:09
# | Designator | Quantity | Comment | Description | Manufacturer 1 | Manufacturer Part Number 1 | #Column Name Error:' Package / Case | Supplier 1 | Supplier Part Number 1
1 | C1, C2 | 2 | 100uF/10V | Cap Aluminum 100uF 10V 20% (5 X 5.4mm) SMD 50mA 1000 hr 85°C T/R |  |  |  | Digi-Key | PCE3867CT-ND
2 | C3, C12, C13, C19, C21, C22, C34 | 7 | 10uF/16V | CERAMIC CAPACITOR, 10UF, 16V, X5R, 20%, 0805, FULL REEL; Product Range:C Series; Capacitance:10 F; Capacitance Tolerance: 20%; Dielectric Characteristic:X5R; Voltage Rating:16V; Ceramic Capacitor Case:0805 [2012 Metric]; MSL:- ;RoHS Compliant: Yes |  |  |  | Digi-Key | 445-4115-2-ND
3 | C4, C5, C6, C8, C11, C14, C15, C16, C17, C20, C23, C24, C26, C28, C29, C30, C31, C32, C33 | 19 | 100nF/50V | TDK - C2012X7R1H104K085AA - SMD Multilayer Ceramic Capacitor, 0.1 µF, 50 V, 0805 [2012 Metric], ± 10%, X7R, C Series |  |  |  | Digi-Key | 445-7534-1-ND
4 | C7 | 1 | 1uF/25V | TDK - C2012X5R1E105K125AA - SMD Multilayer Ceramic Capacitor, 1 µF, 25 V, 0805 [2012 Metric], ± 10%, X5R, C Series |  |  |  | Digi-Key | 445-1419-1-ND
5 | C9, C10, C25, C27 | 4 | 18pF/50V | CAP CER 18PF 50V C0G/NP0 0805 |  |  |  | Digi-Key | 399-1112-1-ND
6 | D1 | 1 | Green | LED Uni-Color Green 572nm 2-Pin Chip 0603(1608Metric) T/R |  |  |  | Digi-Key | 475-2709-1-ND
7 | D2, D3, D4 | 3 | Orange | OSRAM - LO L29K-H2K1-24-Z - SMARTLED 0603 ORANGE |  |  |  | Digi-Key | 475-2740-2-ND
8 | D5, D6 | 2 | BAT54HT1G | Small Signal Schottky Diode, Single, 30 V, 200 mA, 800 mV, 600 mA, 150 C ;RoHS Compliant: Yes |  |  |  | Digi-Key | BAT54HT1GOSCT-ND
9 | FB1, FB2, FB3 | 3 | MPZ2012S601AT000 | FERRITE BEAD 600 OHM 0805 1LN |  |  |  | Digi-Key | 445-2206-1-ND
10 | J1, J3 | 2 | HDR FEMALE 1x8 2.54mm | 2.54mm (0.1") Pitch SIL Vertical PC Tail Socket Assembly, selective gold + tin, 8 contacts |  |  |  | Digi-Key | 952-1823-ND
11 | J2 | 1 | HDR FEMALE 1x6 2.54mm | 06-WAY SIL VERT SOCKET L/FREE |  |  |  | Digi-Key | 952-1809-ND
12 | J4 | 1 | HDR FEMALE 1x10 2.54mm | HARWIN - M20-7821046 - Board-To-Board Connector, M20 Series, Through Hole, Receptacle, 10, 2.54 mm, Tin Plated Contacts |  |  |  | Digi-Key | 952-1847-ND
13 | J5, J6 | 2 | HDR_MALE_2x3 | Conn Unshrouded Header HDR 6 POS 2.54mm Solder ST Thru-Hole Bag |  |  |  | Digi-Key | 952-2121-ND
14 | J7 | 1 | 10118193-0001LF | CONN USB MICRO B RECPT SMT R/A |  |  |  | Digi-Key | 609-4616-1-ND
15 | JP1 | 1 | HDR_MALE_1x3 | CONN HEADER VERT 3POS 2.54MM |  |  |  | Digi-Key | 952-2264-ND
16 | JP3 | 1 | HDR_MALE_1x4 | 04 SIL Vert Pin Hdr |  |  |  | Digi-Key | 952-2266-ND
17 | L1 | 1 | 2u2/2A | FIXED IND 2.2UH 2A 80 MOHM SMD |  |  |  | Digi-Key | 399-9598-1-ND
18 | LINK1, LINK2 | 2 | LINK | CONN JUMPER SHORTING .100" GOLD |  |  |  | Digi-Key | S9337-ND
19 | R1 | 1 | 100k | YAGEO RC0805FR-07100KL RES, THICK FILM, 100K, 1%, 0.125W, 0805, REEL |  |  |  | Digi-Key | 311-100KCRCT-ND
20 | R2, R3, R15, R17, R22 | 5 | 560 | Surface Mount Thick Film Resistor, RC Series, 560 ohm, 125 mW, - 1%, 150 V, 0805 [2012 Metric] |  |  |  | Digi-Key | 311-560CRCT-ND
21 | R4, R14, R18, R19, R20, R21 | 6 | 10k | RES SMD 10K OHM 1% 1/8W 0805 |  |  |  | Digi-Key | 311-10.0KCRCT-ND
22 | R5, R6, R7, R13, R23, R24, R25 | 7 | 22 | RES SMD 22 OHM 1% 1/8W 0805 |  |  |  | Digi-Key | 311-22.0CRCT-ND
23 | R8, R27 | 2 | 0 | Surface Mount Thick Film Resistor, RC Series, 125 mW, - 5%, 150 V, 0805 [2012 Metric] |  |  |  | Digi-Key | 311-0.0ARCT-ND
24 | R9, R16 | 2 | 1M | RES SMD 1M OHM 1% 1/8W 0805 |  |  |  | Digi-Key | 311-1.00MCRCT-ND
25 | R10, R11, R12 | 3 | 1k | RESISTOR, 0805 1K 1%, FULL REEL; Product Range:YAGEO - RC Series; Resistance:1kohm; Power Rating:125mW; Resistance Tolerance:± 1%; Resistor Case Style:0805 [2012 Metric]; Resistor Element Material:Thick Film; Temperature Coefficient:± 250ppm/°C; Voltage Rating:150V; Packaging:Tape & Reel; MSL:-; SVHC:No SVHC (16-Dec-2013); External Depth:0.55mm; External Length / Height:2mm; External Width:1.25mm; No. of Pins:2; Operating Temperature Max:155°C; Operating Temperature Min:-55°C; Operating Temperature Range:-55°C to +155°C; Reel Quantity:5000; Resistor Mounting:SMD; Series:RC12H; Temperature Coef |  |  |  | Digi-Key | 311-1.00KCRCT-ND
26 | SCKET FOR U1 | 1 | 28 Pin DIP Socket | CONN IC DIP SOCKET 28POS TIN |  |  |  | Digi-Key | 3M5480-ND
27 | SW1, SW2 | 2 | 1825910-6 | SWITCH TACTILE SPST-NO 0.05A 24V |  |  |  | Digi-Key | 450-1650-ND
28 | U1 | 1 | ATMEGA328P-PU | ATMEGA328P-PU; 8 bit Microcontroller AVR 20MHz 1; 32kb Flash; 2kb RAM; I2C SPI 2 |  |  |  | Digi-Key | ATMEGA328P-PU-ND
29 | U2 | 1 | ATMEGA16U2-AU | MICROCHIP - ATMEGA16U2-AU - MCU, 8BIT, MEGAAVR, 16MHZ, TQFP-32 |  |  |  | Digi-Key | ATMEGA16U2-AU-ND
30 | U3 | 1 | TL1963A-33DCQR | IC REG LINEAR 3.3V 1.5A SOT223-6 |  |  |  | Digi-Key | 296-24534-1-ND
31 | U4, U5, U6, U7 | 4 | SN74AHC1G09DBVR | TEXAS INSTRUMENTS - SN74AHC1G09DBVR - AND Gate, 74AHC1G09, 2 Input, 2 V to 5.5 V, SOT-23-5 |  |  |  | Digi-Key | 296-29202-1-ND
32 | Y1, Y2 | 2 | ABM7-16.000MHZ-D2Y-T | CRYSTAL 16.0000MHZ 18PF SMD |  |  |  | Digi-Key | 535-9840-1-ND
33 | Z1, Z2 | 2 | CG0603MLC-05E | VARISTOR 0603 |  |  |  | Digi-Key | CG0603MLC-05ECT-ND
Approved |  |  |  |  | Notes

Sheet: Project Information
Project Full Path | C:\Users\Public\Documents\Altium\Projects\28pins_Project_V1I1\28pins_Project_V1I1.PrjPcb
Project Filename | 28pins_Project_V1I1.PrjPcb
Variant Name | FIXED 5V
Data-Source Filename | 28pins_Project_V1I1.PrjPcb
Data-Source Full Path | C:\Users\Public\Documents\Altium\Projects\28pins_Project_V1I1\28pins_Project_V1I1.PrjPcb
Title | 28pins_Project_V1I1.PrjPcb
Total Quantity | 94
Report Time | 11:57 AM
Report Date | 07-Sep-20
Report Date & Tine | 07-Sep-20 11:57 AM
Output Name | 28 Pins_ComponentReference_Grouped_BOM
Output Type | BOM_PartType
Output Generator Name | BOM
Output Generator Description | Bill of Materials

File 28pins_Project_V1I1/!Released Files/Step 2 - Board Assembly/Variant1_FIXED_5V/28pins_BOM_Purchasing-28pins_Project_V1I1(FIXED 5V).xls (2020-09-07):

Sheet: Part List Report
 | Component list |  |  | 28pins_BOM_Purchasing for Variant [FIXED 5V] of Project [28pins_Project_V1I1.PrjPcb] (No PCB Document Selected)
 | Source Data From: | 28pins_Project_V1I1.PrjPcb |  |  | Contact: |  |  |  | Generated by:
 | Project: | 28pins_Project_V1I1.PrjPcb
 | Variant: | FIXED 5V |  |  |  |  |  |  | FEDEVEL
 | Report Date: | 07-Sep-20 | 11:41 AM |  |  |  |  |  | http://www.fedevel.com
 | Print Date: | 2020-09-07 | 11:41:22
# | Category | Manufacturer 1 | Manufacturer Part Number 1 | #Column Name Error:' Package / Case | Description | Quantity | Supplier 1 | Supplier Part Number 1 | Supplier Order Qty 1 | Supplier Stock 1 | Supplier Unit Price 1 | Supplier Subtotal 1 | Supplier Currency 1
1 | Aluminum Electrolytic Capacitors | Panasonic | EEE-1AA101WR |  | Cap Aluminum 100uF 10V 20% (5 X 5.4mm) SMD 50mA 1000 hr 85°C T/R | 2 | Digi-Key | PCE3867CT-ND | 2000 | 0 | 0.10 | 190.56 | USD
2 | Ceramic Capacitors | KEMET | C0805C180J5GACTU |  | CAP CER 18PF 50V C0G/NP0 0805 | 4 | Digi-Key | 399-1112-1-ND | 4000 | 106188 | 0.03 | 103.88 | USD
3 | Ceramic Capacitors | TDK | C2012X5R1C106M125AC |  | CERAMIC CAPACITOR, 10UF, 16V, X5R, 20%, 0805, FULL REEL; Product Range:C Series; Capacitance:10 F; Capacitance Tolerance: 20%; Dielectric Characteristic:X5R; Voltage Rating:16V; Ceramic Capacitor Case:0805 [2012 Metric]; MSL:- ;RoHS Compliant: Yes | 7 | Digi-Key | 445-4115-2-ND |  | 0
4 | Ceramic Capacitors | TDK | C2012X5R1E105K125AA |  | TDK - C2012X5R1E105K125AA - SMD Multilayer Ceramic Capacitor, 1 µF, 25 V, 0805 [2012 Metric], ± 10%, X5R, C Series | 1 | Digi-Key | 445-1419-1-ND | 1000 | 10404 | 0.05 | 53.43 | USD
5 | Ceramic Capacitors | TDK | C2012X7R1H104K085AA |  | TDK - C2012X7R1H104K085AA - SMD Multilayer Ceramic Capacitor, 0.1 µF, 50 V, 0805 [2012 Metric], ± 10%, X7R, C Series | 19 | Digi-Key | 445-7534-1-ND | 19000 | 77861 | 0.03 | 592.04 | USD
6 | Chip SMD Resistors | Yageo | RC0805FR-071ML |  | RES SMD 1M OHM 1% 1/8W 0805 | 2 | Digi-Key | 311-1.00MCRCT-ND | 2000 | 2904634 | 0.01 | 14.10 | USD
7 | Chip SMD Resistors | Yageo | RC0805FR-0710KL |  | RES SMD 10K OHM 1% 1/8W 0805 | 6 | Digi-Key | 311-10.0KCRCT-ND | 6000 | 18879489 | 0.01 | 36.72 | USD
8 | Chip SMD Resistors | Yageo | RC0805FR-0722RL |  | RES SMD 22 OHM 1% 1/8W 0805 | 7 | Digi-Key | 311-22.0CRCT-ND | 7000 | 726288 | 0.01 | 42.84 | USD
9 | Chip SMD Resistors | Yageo | RC0805FR-071KL |  | RESISTOR, 0805 1K 1%, FULL REEL; Product Range:YAGEO - RC Series; Resistance:1kohm; Power Rating:125mW; Resistance Tolerance:± 1%; Resistor Case Style:0805 [2012 Metric]; Resistor Element Material:Thick Film; Temperature Coefficient:± 250ppm/°C; Voltage Rating:150V; Packaging:Tape & Reel; MSL:-; SVHC:No SVHC (16-Dec-2013); External Depth:0.55mm; External Length / Height:2mm; External Width:1.25mm; No. of Pins:2; Operating Temperature Max:155°C; Operating Temperature Min:-55°C; Operating Temperature Range:-55°C to +155°C; Reel Quantity:5000; Resistor Mounting:SMD; Series:RC12H; Temperature Coef | 3 | Digi-Key | 311-1.00KCRCT-ND | 3000 | 17121857 | 0.01 | 18.36 | USD
10 | Chip SMD Resistors | Yageo | RC0805JR-070RL |  | Surface Mount Thick Film Resistor, RC Series, 125 mW, - 5%, 150 V, 0805 [2012 Metric] | 2 | Digi-Key | 311-0.0ARCT-ND | 2000 | 6462563 | 0.01 | 12.14 | USD
11 | Chip SMD Resistors | Yageo | RC0805FR-07560RL |  | Surface Mount Thick Film Resistor, RC Series, 560 ohm, 125 mW, - 1%, 150 V, 0805 [2012 Metric] | 5 | Digi-Key | 311-560CRCT-ND | 5000 | 63787 | 0.01 | 30.60 | USD
12 | Chip SMD Resistors | Yageo | RC0805FR-07100KL |  | YAGEO RC0805FR-07100KL RES, THICK FILM, 100K, 1%, 0.125W, 0805, REEL | 1 | Digi-Key | 311-100KCRCT-ND | 1000 | 3595607 | 0.01 | 7.05 | USD
13 | Connectors | 3M | 7010501790 |  | CONN IC DIP SOCKET 28POS TIN | 1 | Digi-Key | 3M5480-ND | 1000 | 4151 | 0.44 | 435.04 | USD
14 | Connectors | Sullins | QPC02SXGN-RC |  | CONN JUMPER SHORTING .100" GOLD | 2 | Digi-Key | S9337-ND | 2000 | 946042 | 0.03 | 52.92 | USD
15 | Crystals | Abracon | ABM7-16.000MHZ-D2Y-T |  | CRYSTAL 16.0000MHZ 18PF SMD | 2 | Digi-Key | 535-9840-1-ND | 2000 | 61236 | 0.67 | 1330.56 | USD
16 | Ferrite Beads and Chips | TDK | MPZ2012S601AT000 |  | FERRITE BEAD 600 OHM 0805 1LN | 3 | Digi-Key | 445-2206-1-ND | 3000 | 204933 | 0.03 | 90.60 | USD
17 | Fixed Inductors | KEMET | L1210R2R2MDWIT |  | FIXED IND 2.2UH 2A 80 MOHM SMD | 1 | Digi-Key | 399-9598-1-ND | 1000 | 0 | 0.26 | 264.90 | USD
18 | Headers and Wire Housings | Harwin | M20-7820842 |  | 2.54mm (0.1") Pitch SIL Vertical PC Tail Socket Assembly, selective gold + tin, 8 contacts | 2 | Digi-Key | 952-1823-ND | 2000 | 1791 | 0.61 | 1219.20 | USD
19 | Headers and Wire Housings | Harwin | M20-9990446 |  | 04 SIL Vert Pin Hdr | 1 | Digi-Key | 952-2266-ND | 1000 | 10489 | 0.08 | 79.80 | USD
20 | Headers and Wire Housings | Harwin | M20-7820646 |  | 06-WAY SIL VERT SOCKET L/FREE | 1 | Digi-Key | 952-1809-ND | 1000 | 2253 | 0.53 | 528.00 | USD
21 | Headers and Wire Housings | Harwin | M20-9990346 |  | CONN HEADER VERT 3POS 2.54MM | 1 | Digi-Key | 952-2264-ND | 1000 | 10178 | 0.06 | 60.90 | USD
22 | Headers and Wire Housings | Harwin | M20-9980346 |  | Conn Unshrouded Header HDR 6 POS 2.54mm Solder ST Thru-Hole Bag | 2 | Digi-Key | 952-2121-ND | 2000 | 18252 | 0.11 | 219.60 | USD
23 | Headers and Wire Housings | Harwin | M20-7821046 |  | HARWIN - M20-7821046 - Board-To-Board Connector, M20 Series, Through Hole, Receptacle, 10, 2.54 mm, Tin Plated Contacts | 1 | Digi-Key | 952-1847-ND | 1000 | 544 | 0.70 | 704.00 | USD
24 | Logic Gates | Texas Instruments | SN74AHC1G09DBVR |  | TEXAS INSTRUMENTS - SN74AHC1G09DBVR - AND Gate, 74AHC1G09, 2 Input, 2 V to 5.5 V, SOT-23-5 | 4 | Digi-Key | 296-29202-1-ND | 4000 | 27471 | 0.07 | 276.00 | USD
25 | Microcontrollers | Microchip / Atmel | ATMEGA328P-PU |  | ATMEGA328P-PU; 8 bit Microcontroller AVR 20MHz 1; 32kb Flash; 2kb RAM; I2C SPI 2 | 1 | Digi-Key | ATMEGA328P-PU-ND | 1000 | 7983 | 1.73 | 1730.00 | USD
26 | Microcontrollers | Microchip | ATMEGA16U2-AU |  | MICROCHIP - ATMEGA16U2-AU - MCU, 8BIT, MEGAAVR, 16MHZ, TQFP-32 | 1 | Digi-Key | ATMEGA16U2-AU-ND | 1000 | 3827 | 2.04 | 2040.00 | USD
27 | Pushbutton Switches | TE Connectivity | FSM4JH |  | SWITCH TACTILE SPST-NO 0.05A 24V | 2 | Digi-Key | 450-1650-ND | 2000 | 120386 | 0.06 | 125.30 | USD
28 | Schottky Diodes | ON Semiconductor / Fairchild | BAT54HT1G |  | Small Signal Schottky Diode, Single, 30 V, 200 mA, 800 mV, 600 mA, 150 C ;RoHS Compliant: Yes | 2 | Digi-Key | BAT54HT1GOSCT-ND | 2000 | 207241 | 0.03 | 63.48 | USD
29 | Uncategorized | Osram Opto | LGL29K-G2J1-24-Z |  | LED Uni-Color Green 572nm 2-Pin Chip 0603(1608Metric) T/R | 1 | Digi-Key | 475-2709-1-ND | 1000 | 0 | 0.12 | 118.32 | USD
30 | Uncategorized | Osram Opto | LOL29K-H2K1-24-Z |  | OSRAM - LO L29K-H2K1-24-Z - SMARTLED 0603 ORANGE | 3 | Digi-Key | 475-2740-2-ND |  | 0
31 | USB Connectors | AMPHENOL ICC (FCI) | 10118193-0001LF |  | CONN USB MICRO B RECPT SMT R/A | 1 | Digi-Key | 609-4616-1-ND | 1000 | 129838 | 0.27 | 270.16 | USD
32 | Varistors | Bourns | CG0603MLC-05E |  | VARISTOR 0603 | 2 | Digi-Key | CG0603MLC-05ECT-ND | 2000 | 97120 | 0.06 | 128.60 | USD
33 | Voltage Regulators - Linear | Texas Instruments | TL1963A-33DCQR |  | IC REG LINEAR 3.3V 1.5A SOT223-6 | 1 | Digi-Key | 296-24534-1-ND | 1000 | 2737 | 1.40 | 1404.48 | USD
 |  |  |  |  |  | 94 |  |  | 84000 |  |  | 12243.58
Approved |  |  |  | Notes
 |  |  |  |  |  | 1000 | pcs: | Total |  | 12243.58 |  | USD
 |  |  |  |  |  |  |  | Price for 1pcs |  | 12.24 |  | USD

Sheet: Project Information
Project Full Path | C:\Users\Public\Documents\Altium\Projects\28pins_Project_V1I1\28pins_Project_V1I1.PrjPcb
Project Filename | 28pins_Project_V1I1.PrjPcb
Variant Name | FIXED 5V
Data-Source Filename | 28pins_Project_V1I1.PrjPcb
Data-Source Full Path | C:\Users\Public\Documents\Altium\Projects\28pins_Project_V1I1\28pins_Project_V1I1.PrjPcb
Title | 28pins_BOM_Purchasing for Variant [FIXED 5V] of Project [28pins_Project_V1I1.PrjPcb] (No PCB Document Selected)
Total Quantity | 94
Report Time | 11:41 AM
Report Date | 07-Sep-20
Report Date & Tine | 07-Sep-20 11:41 AM
Output Name | 28pins_BOM_Purchasing
Output Type | BOM_PartType
Output Generator Name | BOM
Output Generator Description | Bill of Materials

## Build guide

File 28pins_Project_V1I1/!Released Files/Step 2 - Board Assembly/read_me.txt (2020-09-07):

Place following files here:

- Mechanical Drawing (Board dimensions, holes position, ..)
- TOP and BOTTOM Assembly Drawing (Component position with Reference Designator)
- TOP and BOTTOM VIEW (shows board outline, assembly layer, TOP + BOTTOM layers)
- Bill of Materials (grouped by component type)
- Component reference BOM (each component on one line: Designator, Description, Manufacturer 1,
  Manufacturer, Part Number 1, Package / Case, Supplier 1, Supplier Part Number 1)
- Component reference BOM (as above) grouped by component type.
- Pick and Place
- TOP and BOTTOM Layer + TOP and BOTTOM Paste Gerber Files (for stencil - if panel is done in a PCB house, ask them later for the top/bottom layers and paste for the panel)
- PDF 3D Model

!!! BE AWARE !!! If you use a VARIANT were you replace a component by other component,
THIS WILL NOT BE REFLECTED IN ASSEMBLY DRAWING and component will look like not fitted.
This may be a bug in Altium 14.3. Use a TEMP Schematic to generate the ASM DRWG. SAME
FOR PICK & PLACE!!

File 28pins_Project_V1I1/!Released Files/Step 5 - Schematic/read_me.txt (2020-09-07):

Update Schematic Cover Page to RELEASED DD-MMM-YYYY
Place here PDF version of schematic, if possible one for each BOM variant.

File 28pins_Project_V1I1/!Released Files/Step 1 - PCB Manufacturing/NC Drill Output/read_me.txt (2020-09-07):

Place here drill files and documents which explain it (e.g. for HDI PCB you can put here pdf showing drills for each layer pair)

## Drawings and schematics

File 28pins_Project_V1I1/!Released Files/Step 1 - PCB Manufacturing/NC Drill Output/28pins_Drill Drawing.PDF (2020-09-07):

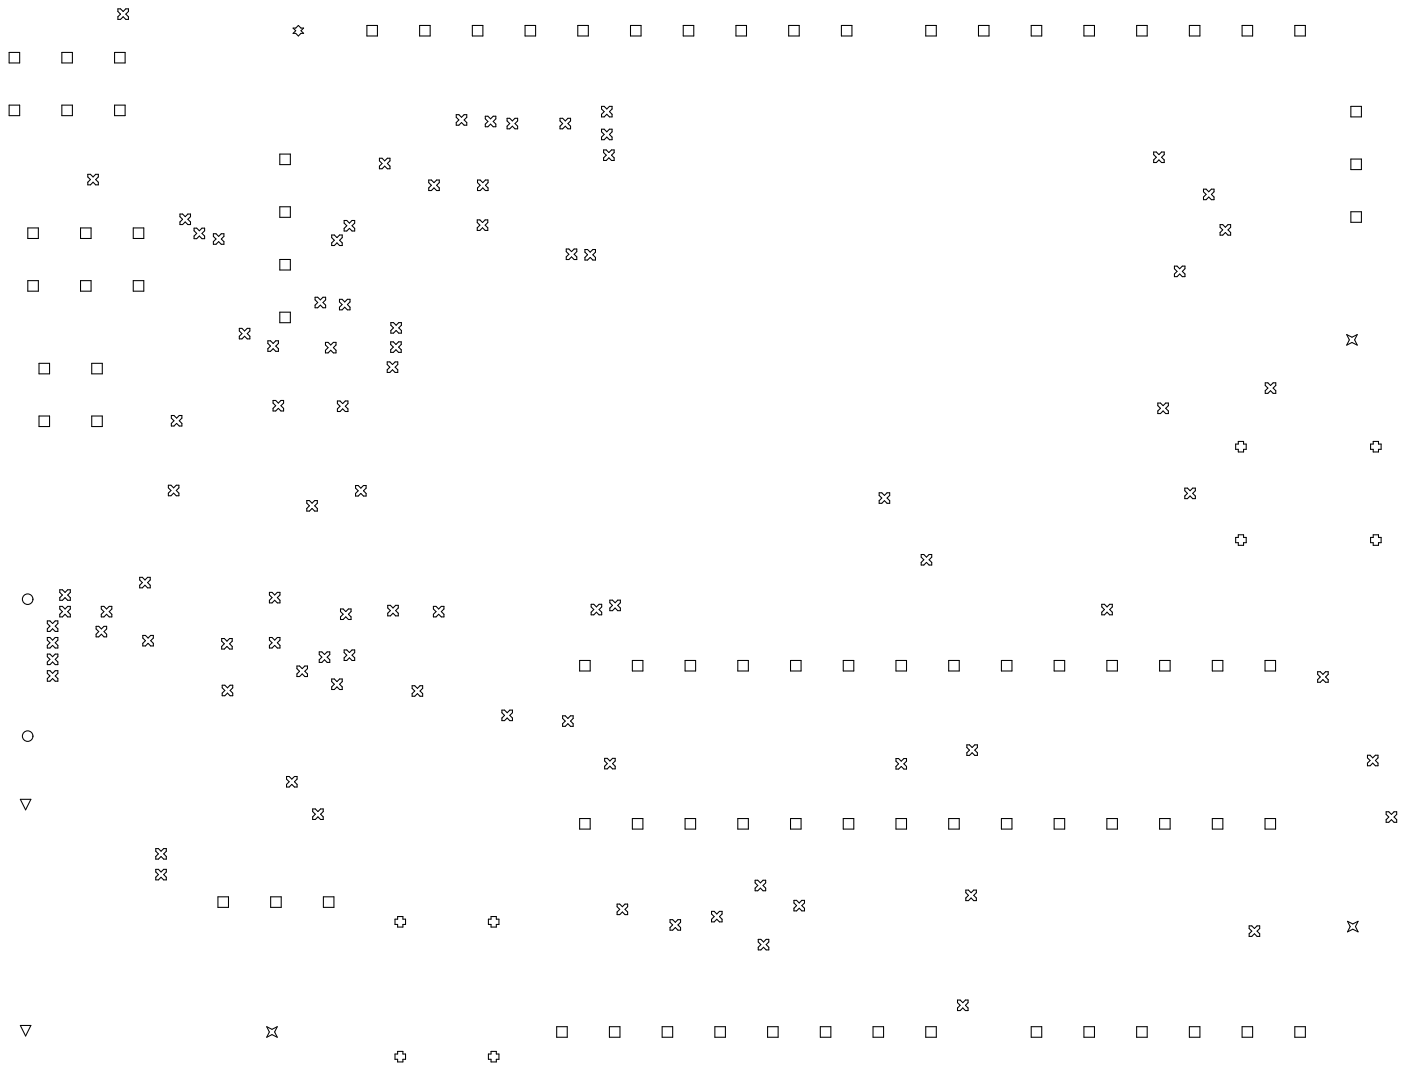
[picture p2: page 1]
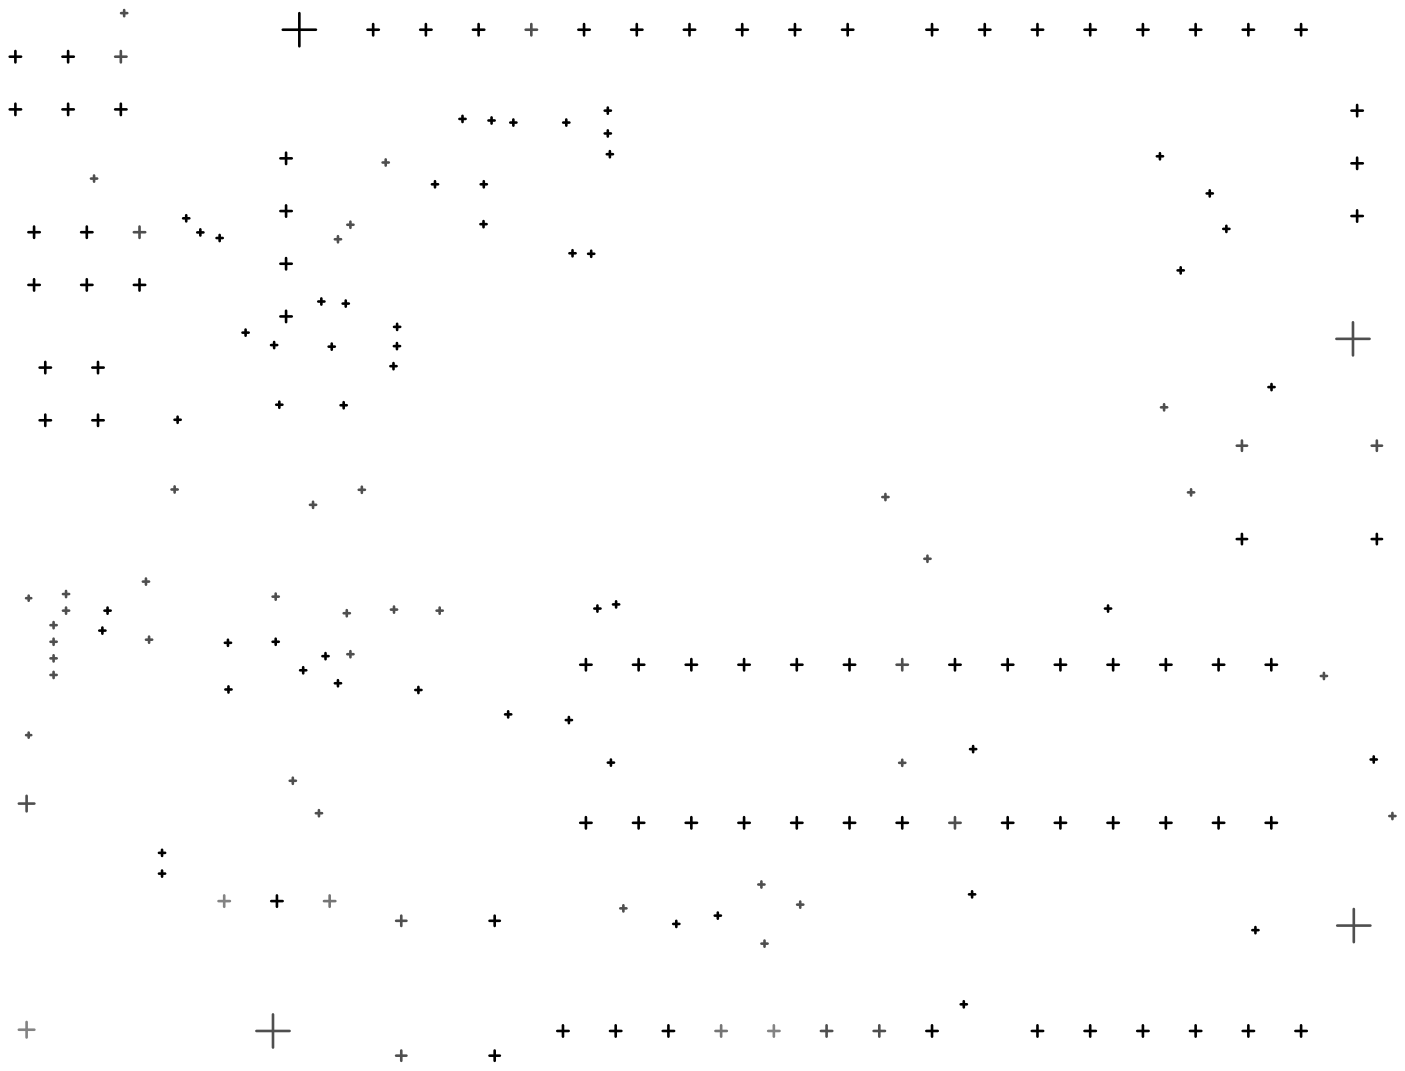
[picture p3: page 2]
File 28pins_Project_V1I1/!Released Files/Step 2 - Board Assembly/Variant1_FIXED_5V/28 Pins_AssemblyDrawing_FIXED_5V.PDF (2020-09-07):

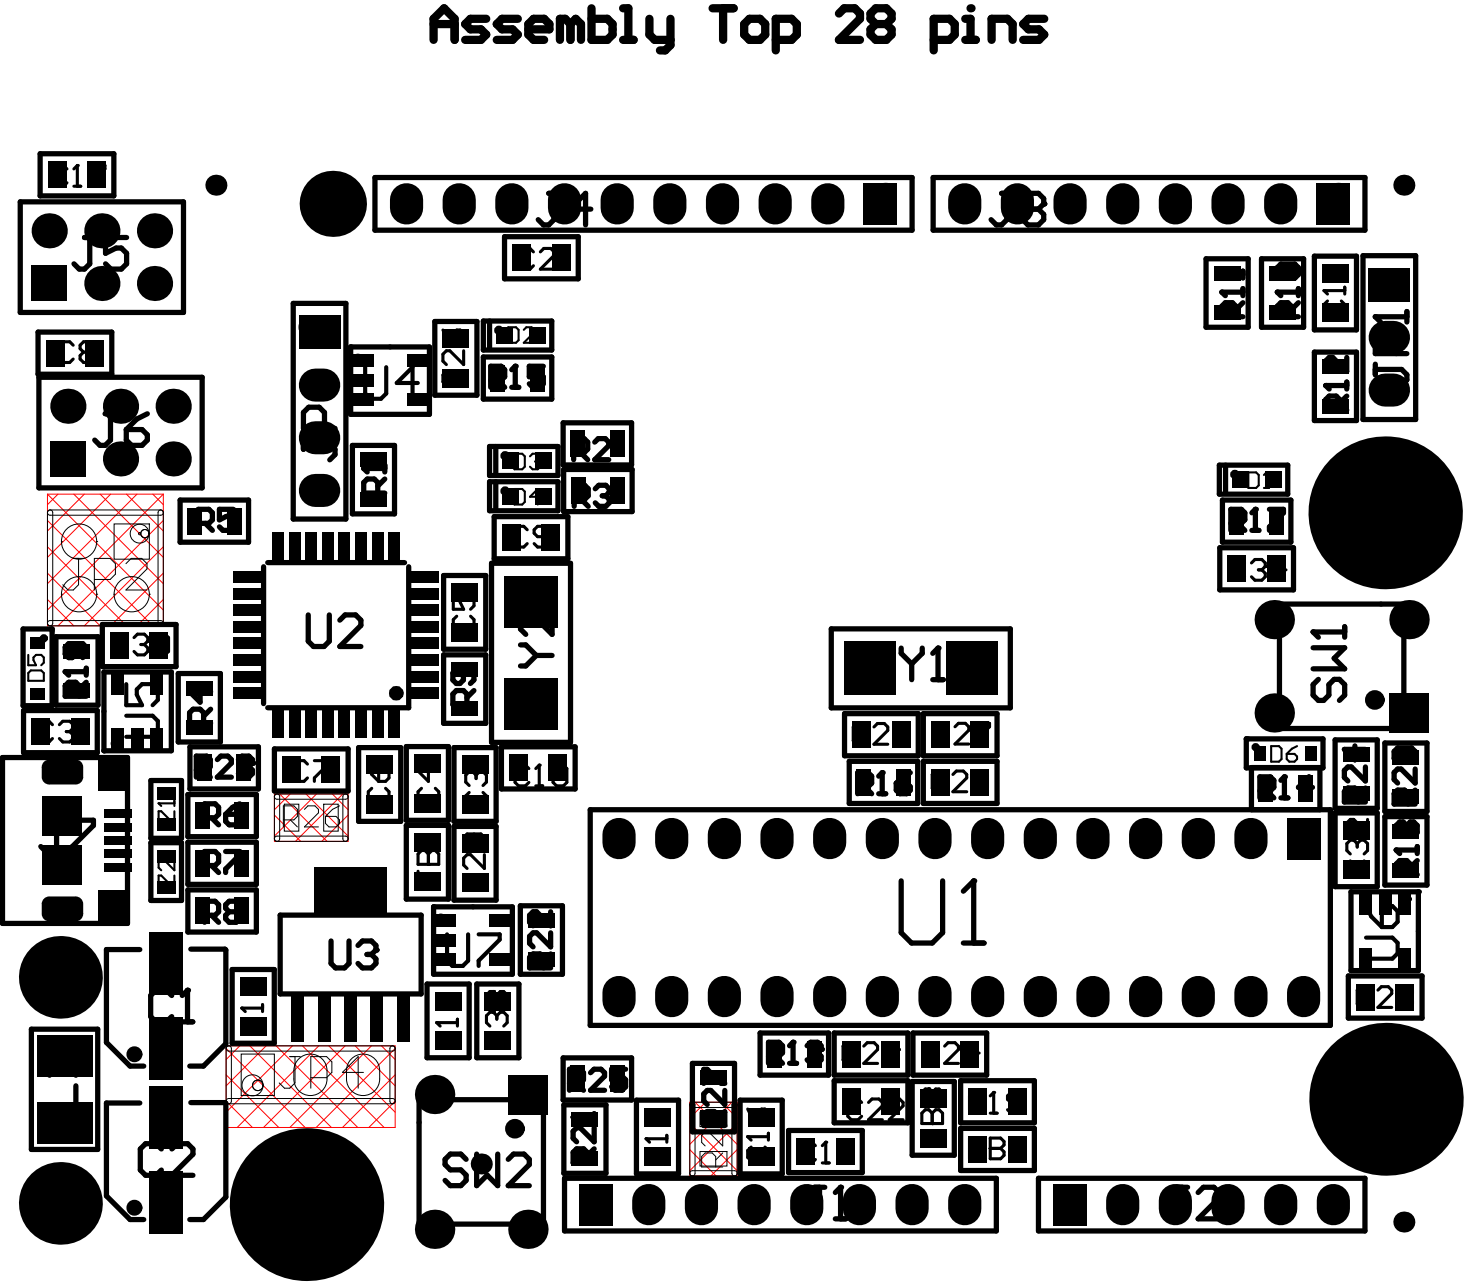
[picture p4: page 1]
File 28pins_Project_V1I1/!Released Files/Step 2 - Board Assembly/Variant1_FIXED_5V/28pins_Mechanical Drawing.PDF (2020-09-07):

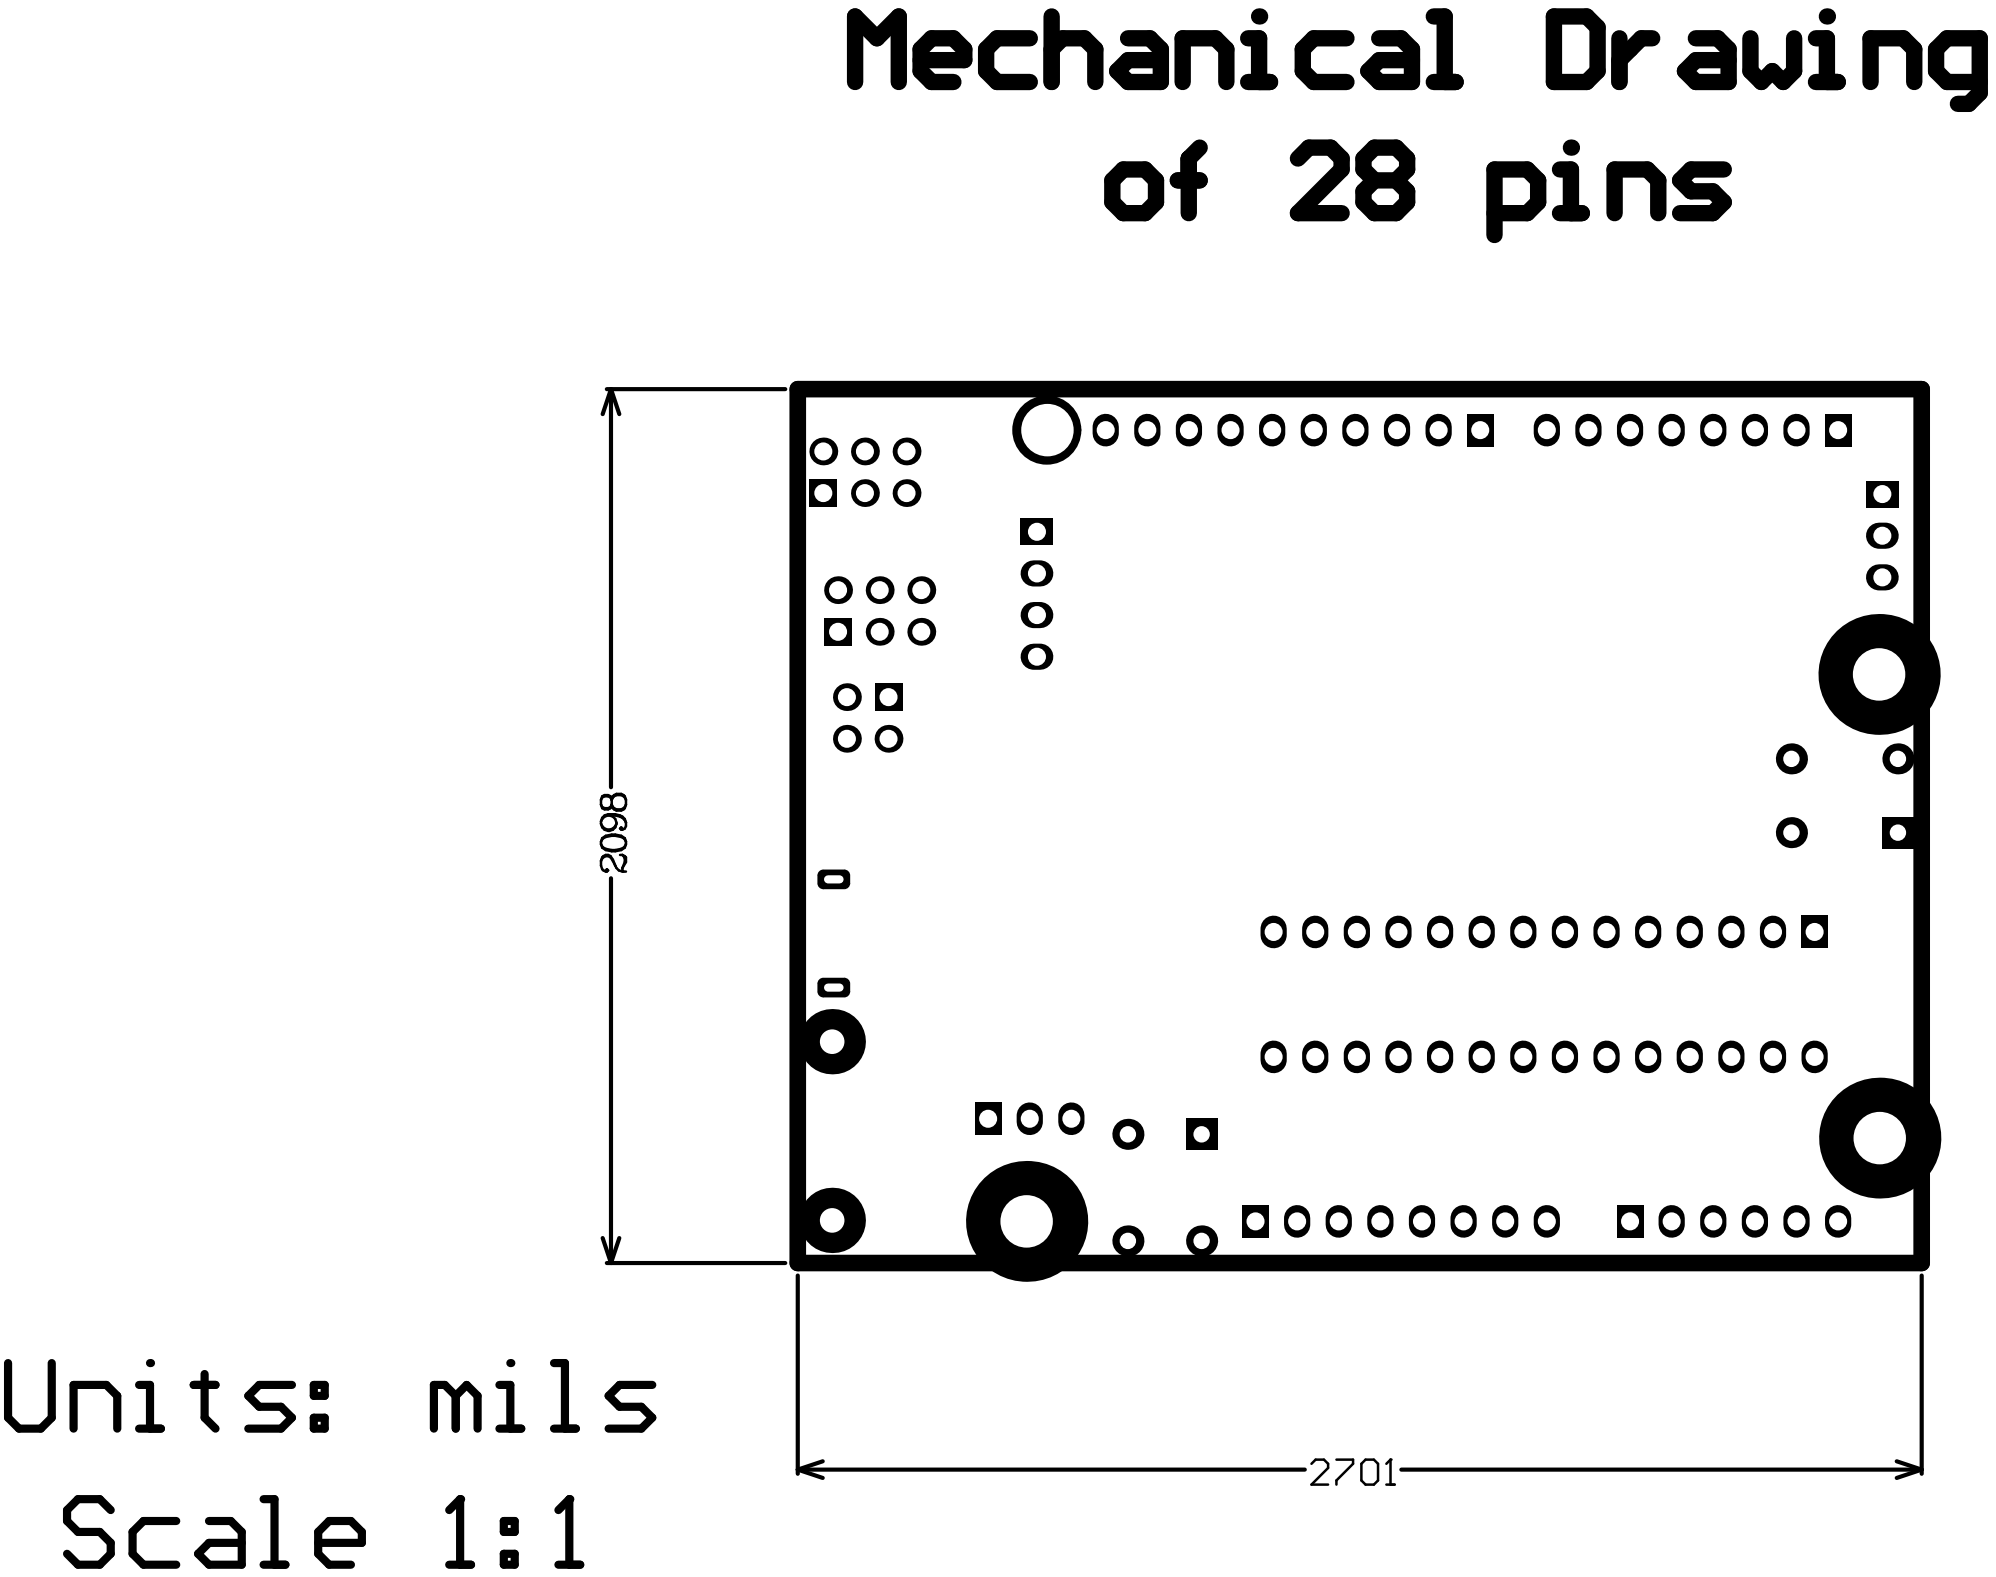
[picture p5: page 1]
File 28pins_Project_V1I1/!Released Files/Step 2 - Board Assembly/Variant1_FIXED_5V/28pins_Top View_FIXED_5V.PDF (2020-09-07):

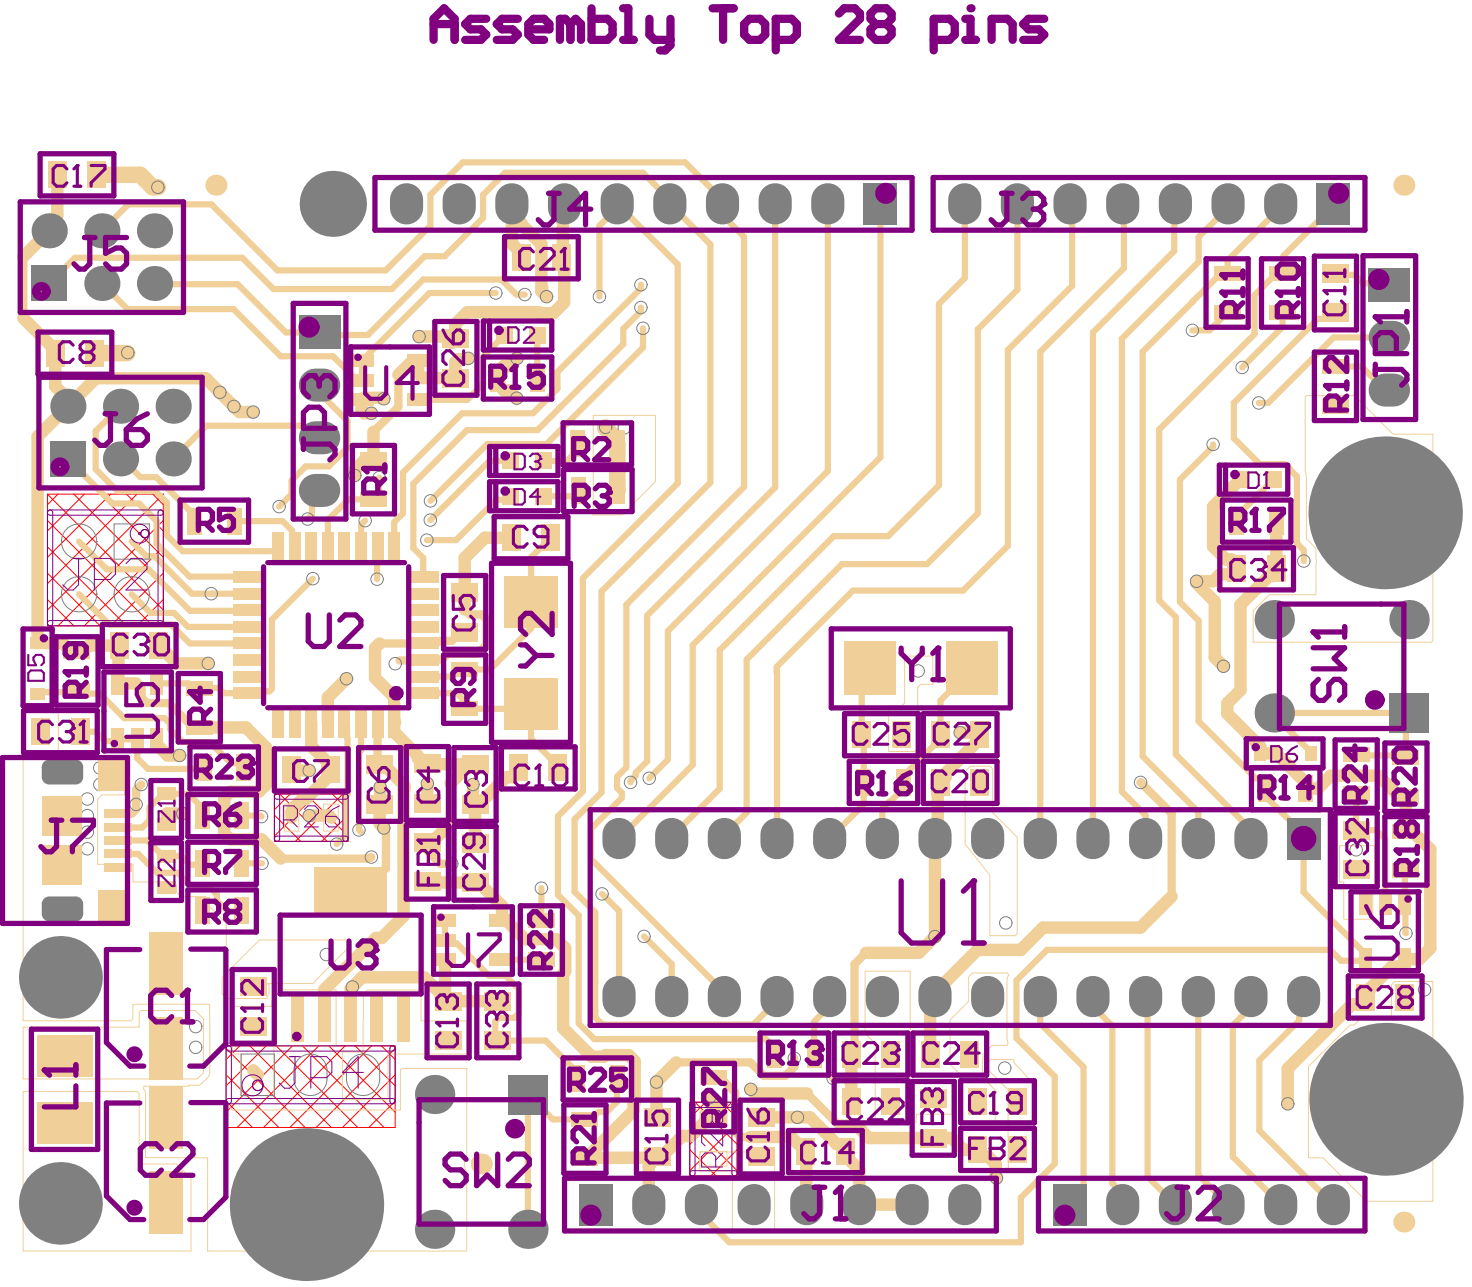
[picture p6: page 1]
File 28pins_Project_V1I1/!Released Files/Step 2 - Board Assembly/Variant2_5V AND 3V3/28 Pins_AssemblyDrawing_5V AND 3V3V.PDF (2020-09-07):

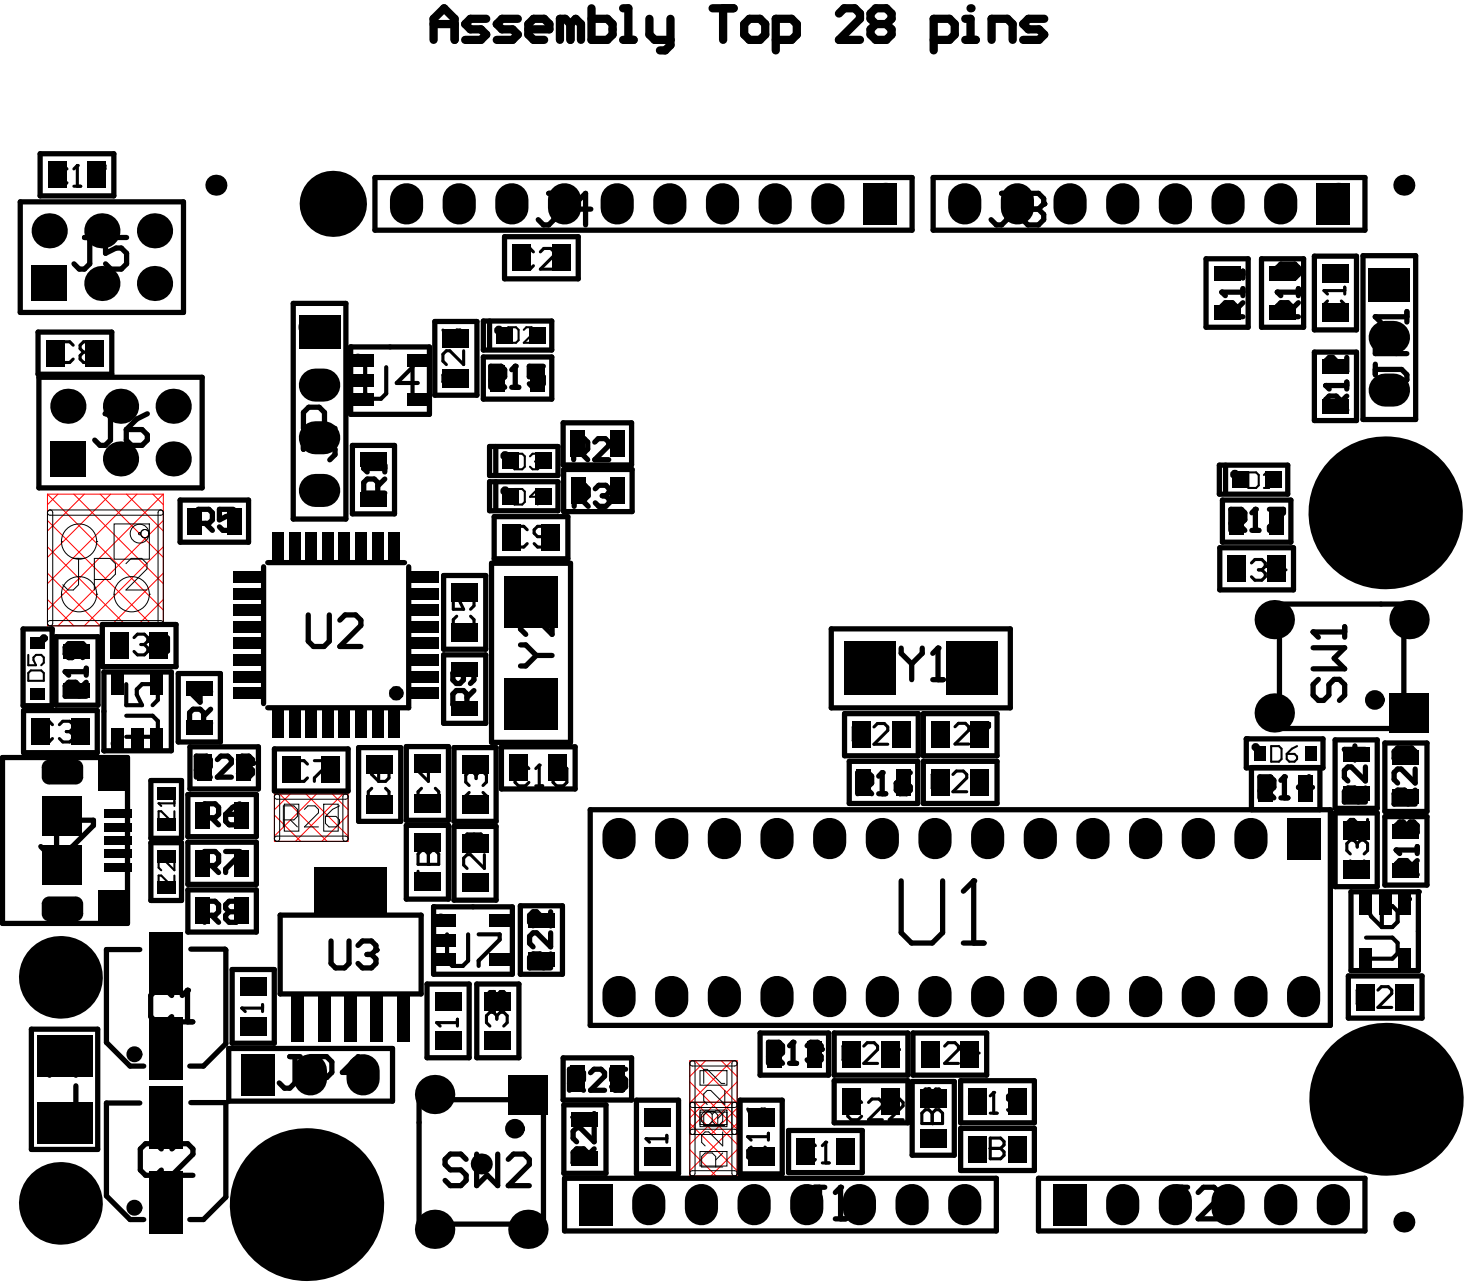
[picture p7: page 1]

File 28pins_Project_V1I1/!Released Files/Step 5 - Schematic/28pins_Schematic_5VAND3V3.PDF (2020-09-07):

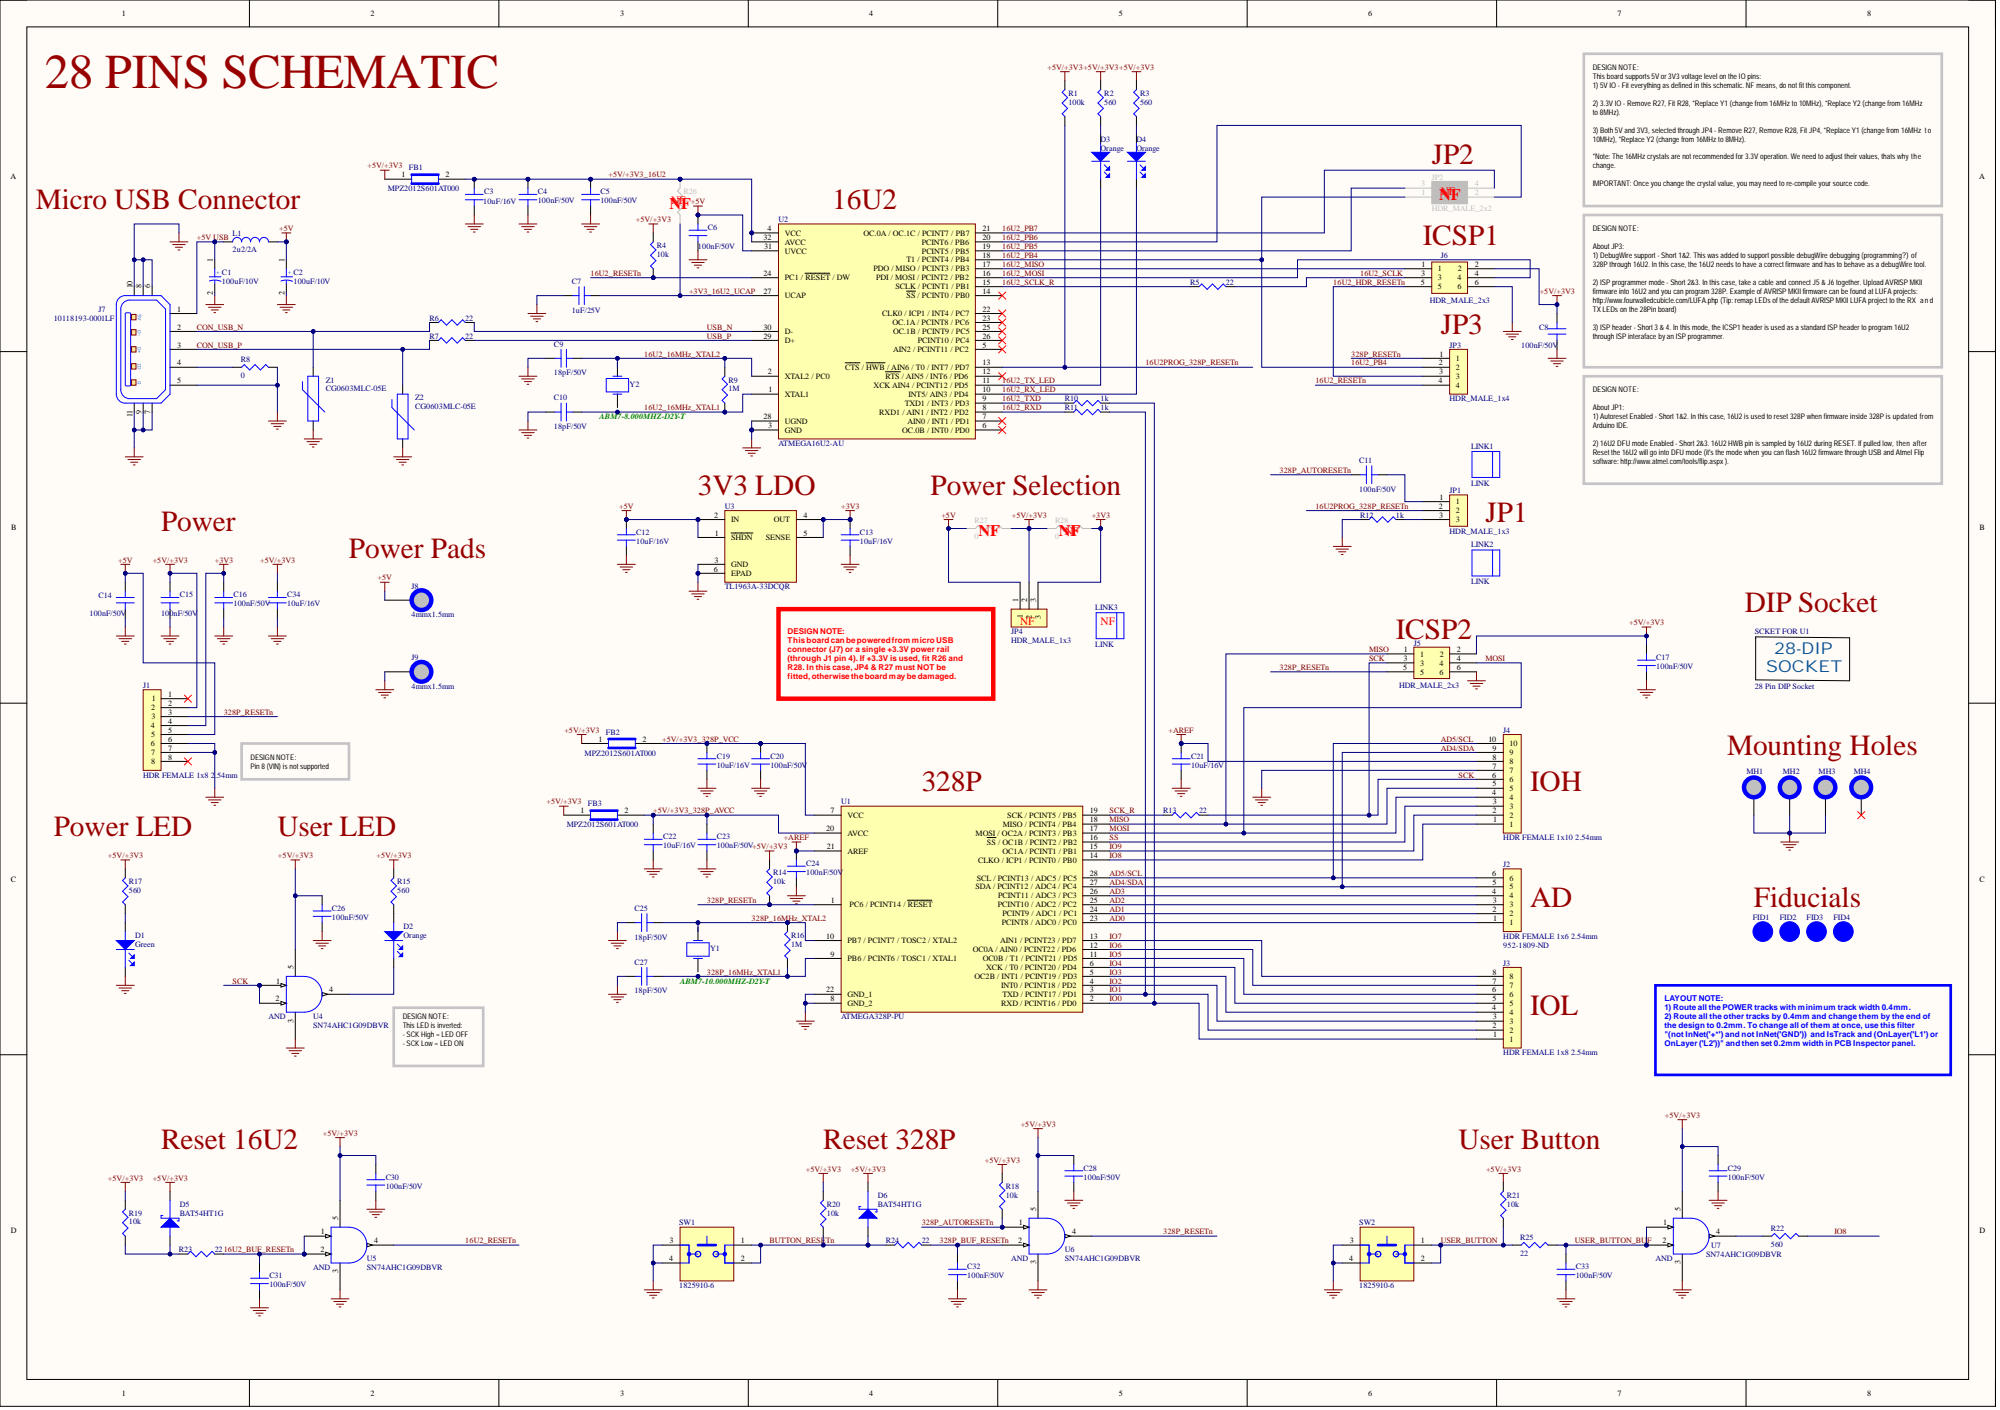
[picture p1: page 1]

DESIGN NOTE:
This board supports 5V or 3V3 voltage level on the IO pins:
1) 5V IO - Fit everything as defined in this schematic. NF means, do not fit this component.

2) 3.3V IO - Remove R27, Fit R28, *Replace Y1 (change from 16MHz to 10MHz), *Replace Y2 (change from 16MHz
to 8MHz).

3) Both 5V and 3V3, selected through JP4 - Remove R27, Remove R28, Fit JP4, *Replace Y1 (change from 16MHz to
10MHz), *Replace Y2 (change from 16MHz to 8MHz).

*Note: The 16MHz crystals are not recommended for 3.3V operation. We need to adjust their values, thats why the
change.

IMPORTANT: Once you change the crystal value, you may need to re-compile your source code.

UVCC 31 AVCC 32 | 16U2_PB6 | ICSP1 J6

About JP3:
1) DebugWire support - Short 1&2. This was added to support possible debugWire debugging (programming?) of
328P through 16U2. In this case, the 16U2 needs to have a correct firmware and has to behave as a debugWire tool.

PC1 / RESET / DW 24 | 16U2_PB4

16U2_MISO | | | | 1 1 2 4 | 2
16U2_MOSI | | | 16U2_SCLK | 3 3 | 4

+3V3_16U2_UCAP | | UCAP 27 | 16U2_TX_LED | | | 16U2_HDR_RESETn

2) ISP programmer mode - Short 2&3. In this case, take a cable and connect J5 & J6 together. Upload AVRISP MKII
firmware into 16U2 and you can program 328P. Example of AVRISP MKII firmware can be found at LUFA projects:
http://www.fourwalledcubicle.com/LUFA.php (Tip: remap LEDs of the default AVRISP MKII LUFA project to the RX and
TX LEDs on the 28Pin board)

3) ISP header - Short 3 & 4. In this mode, the ICSP1 header is used as a standard ISP header to program 16U2
through ISP interaface by an ISP programmer.

328P_RESETn 16U2_PB4

UGND 28 | 16U2_TXD R10 1k

16U2_RXD R11 1k

About JP1:
1) Autoreset Enabled - Short 1&2. In this case, 16U2 is used to reset 328P when firmware inside 328P is updated from
Arduino IDE.

2) 16U2 DFU mode Enabled - Short 2&3. 16U2 HWB pin is sampled by 16U2 during RESET. If pulled low, then after
Reset the 16U2 will go into DFU mode (it's the mode when you can flash 16U2 firmware through USB and Atmel Flip
software: http://www.atmel.com/tools/flip.aspx ).

This board can be powered from micro USB
connector (J7) or a single +3.3V power rail
(through J1 pin 4). If +3.3V is used, fit R26 and
R28. In this case, JP4 & R27 must NOT be
fitted, otherwise the board may be damaged.

SCK | MOSI

Pin 8 (VIN) is not supported

SCK

AREF 21 | | SS

PC6 / PCINT14 / RESET 1 | | IO8

AD5/SCL
AD4/SDA

PB7 / PCINT7 / TOSC2 / XTAL2 10 | | AD1

GND_1 22 | IO4

LAYOUT NOTE:
1) Route all the POWER tracks with minimum track width 0.4mm.
2) Route all the other tracks by 0.4mm and change them by the end of
the design to 0.2mm. To change all of them at once, use this filter
"(not InNet('+*') and not InNet('GND')) and IsTrack and (OnLayer('L1') or
OnLayer('L2'))" and then set 0.2mm width in PCB Inspector panel.

This LED is inverted:
- SCK High = LED OFF
- SCK Low = LED ON
